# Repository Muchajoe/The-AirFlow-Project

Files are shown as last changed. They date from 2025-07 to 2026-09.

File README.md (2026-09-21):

# 💨 THE AIRFLOW PROJECT - ESP32 Smart Fan Controller






An ultra-compact (40x40 mm), intelligent 4-channel fan controller built for PC modding, SFF (Small Form Factor) builds, and smart home integration. **Please read this carefully!**

No proprietary desktop software required: just plug it in, connect to Wi-Fi, and take control immediately via Home Assistant or with your own Arduino code.

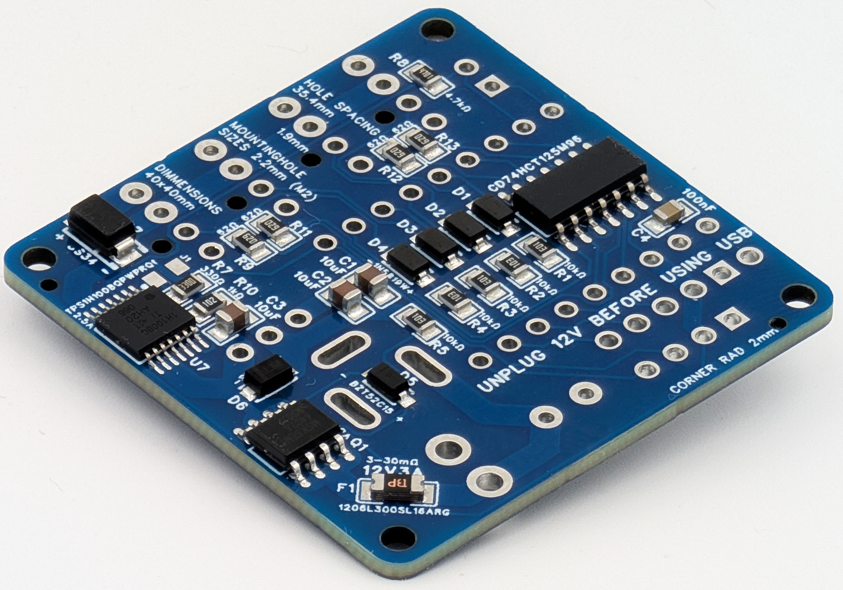
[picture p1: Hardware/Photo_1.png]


---

## 📑 Table of Contents

1. [The AirFlow Project Features](#-features-at-a-glance)
2. [DIY Expansion Port](#-the-hacker-header-diy-expansion-port)
3. [Socketed MCU Design)](#-modular-bring-your-own-brain-architecture)
4. [PWM Signal Integrity ](#-advanced-pwm-signal-integrity-true-5v-push-pull)
5. [Power Input Options](#-flexible-power-input-options)
6. [Hardware Protection](#%EF%B8%8F-ultimate-hardware-protection)
7. [Dimensions & Clearance](#-mechanical-dimensions--clearance)
8. [Getting Started](#-quick-start)
   - [ESPHome / Home Assistant](#option-a-esphome--home-assistant)
   - [Arduino](#option-b-the-arduino-way)
9. [Hardware & Pinout](#-hardware--pinout)
10. [Power Supply](#%EF%B8%8F-power-supply-safety-note)
11. [Troubleshooting](#troubleshooting)
12. [Important Words](#famous-and-important-last-words)
13. [Power Supply](#%EF%B8%8F-power-supply-safety-note)
14. [Troubleshooting](#troubleshooting)
15. [Where to buy (tindie.com)](https://www.tindie.com/products/the-omega-projects/the-airflow-project-esp32-pwm-fan-controller/)
15. [License](#%EF%B8%8F-license)

---

## ✨ Features at a Glance

* **The Brain:** Powered by a high-performance **ESP32-S3 Zero/Mini** (or optional ESP32C3 Zero/Mini or ESP32C6 Zero/Mini (NOT SuperMini)). Provides massive computing power for complex PID controllers, Wi-Fi, and Bluetooth.
* **4x Independent Channels:** Full PWM control and true RPM feedback (tacho signal) for up to four 12V fans.
* **Global Zero-RPM Mode:** Basic controllers often rely on a 0% PWM signal, which many fans ignore by dropping to a minimum idle speed. By acting as a master high-side switch, the eFuse allows the ESP32 to physically cut the 12V power to the entire fan rail at once – ensuring absolute 0dB silence for your whole setup when you don't need cooling.
* **Premium Power Delivery:** Instead of relying on cheap, heat-generating linear regulators (LDOs), this board features a high-end, fully encapsulated K7805-1000R3 switching regulator. This highly efficient (up to 96%) step-down converter guarantees a perfectly stable and icy-cool power supply for the ESP32-S3, ensuring rock-solid 24/7 reliability without any thermal issues. 
* **Overbuilt Power Delivery:** To ensure absolute thermal stability, the main 12V power traces are routed at a massive 1.9 mm width. Even running four [heavy-duty (noctua.at)](https://www.noctua.at/en/products/nf-f12-industrialppc-3000-pwm/specifications) fans at 100% capacity 24/7, the board remains completely cold, for a maximum lifespan of components.
* **Standardized Connectors:** Equipped with genuine Molex 4-pin headers (47053-1000) featuring friction locks. Fully compatible with all standard 4-pin PWM and 3-pin PC fans out of the box – no proprietary adapters required.
* **4x M2 Mounting Holes:** Despite the ultra-compact 40x40 mm footprint, the PCB features four precisely placed M2 mounting holes in the corners. Perfectly prepared for custom 3D-printed enclosures, brass standoffs, or direct integration into your custom PC or SFF chassis. Say goodbye to messy double-sided tape!
* **True Right to Repair (Self-Documenting PCB):** I believe hardware should be repairable. Instead of hiding component identities or forcing you to hunt through digital BOMs, the PCB silkscreen is exhaustively labeled. Every single component features its designator and, where applicable, its exact value printed right next to the pads. If you ever need to probe, modify, or repair the board, the PCB itself is your physical schematic.
* **One More Thing:** [If the airflow settles, there could be room for something brighter](OneMoreThing.md)<br>
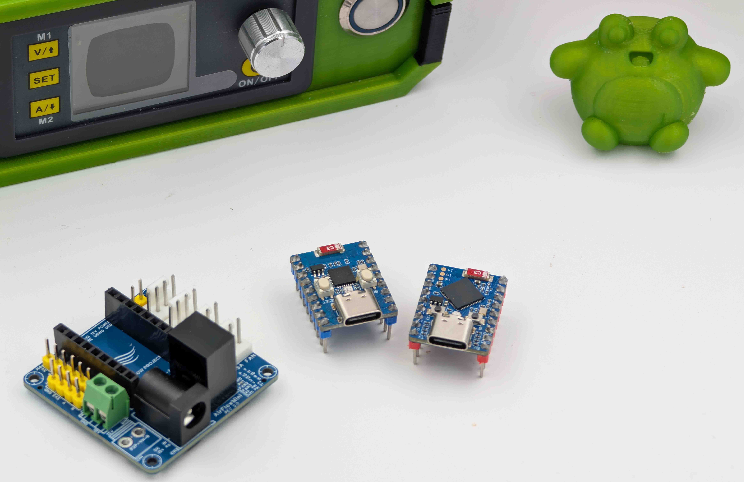
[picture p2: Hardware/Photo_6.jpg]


## 🧰 The "Hacker Header" (DIY Expansion Port)

While the controller is designed to work perfectly right out of the box, I wanted to leave the door wide open for maker, hardware hackers and modders. 

The board features an exposed male pin header that grants direct access to the ESP32's remaining resources:
* **Power Delivery:** Dedicated **5V, 3.3V, and GND** pins. You can power your external modules directly through the board's premium onboard voltage regulator.
* **5x Free GPIOs:** Fully routable pins ready for your custom physical interfaces.
* **Limitless Expansion:** Perfect for adding physical rotary encoders for manual speed tuning, tactile buttons, I2C OLED displays, or custom environmental/air quality sensors to trigger your fans automatically.
* **⚠️ Firmware Note:** Please be aware that this expansion header is provided purely as a hardware playground for tinkerers. These extra pins are *not* implemented in the stock web-interface firmware. They are waiting for you to unleash them via your own custom ESPHome configurations or C++ code!
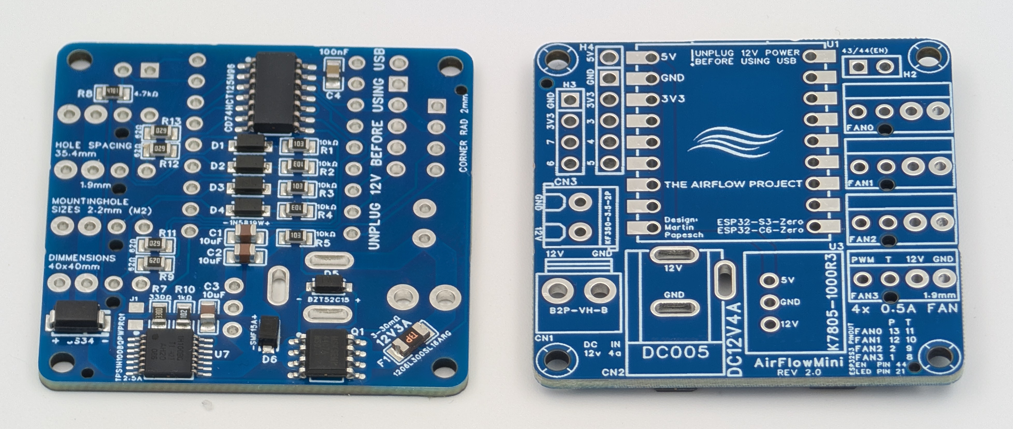
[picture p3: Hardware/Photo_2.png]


## 🧠 Modular "Bring Your Own Brain" Architecture

This board features a **socketed MCU design** based on the popular "Zero" form factor. You own the hardware, and you decide what runs on it.

* **The Default Powerhouse:** The board is designed around the **ESP32-S3 Zero**, providing massive computing power, Wi-Fi, and Bluetooth 5 (LE) for complex local web interfaces and advanced PID fan control.
* **Drop-In Upgrades:** The socket is fully pin-compatible with other microcontrollers in the same form factor, such as the **ESP32-C3 Zero** or **ESP32-C6 Zero**.
* **Next-Gen Smart Home Ready:** By simply swapping the default MCU for an ESP32-C6 Zero, your hardware immediately gains support for **IEEE 802.15.4** wireless standards. This unlocks the physical ability to integrate the controller directly into modern power saving mesh networks!

## 🌊 Advanced PWM Signal Integrity (True 5V Push-Pull)

The original Intel 4-pin fan specification from the early 2000s relies on an open-drain architecture: the controller pulls the PWM signal to Ground and lets it "float" back up, relying entirely on the fan's internal pull-up resistor. While adequate for basic setups, this floating approach often results in degraded, sloppy signal waves—especially when using longer cable runs.

To guarantee flawless motor control, this board utilizes a dedicated **CD74HCT125M96** logic buffer to deliver a strict **5V Push-Pull** PWM signal. 

* **Perfect Square Waves:** Instead of floating, the IC actively drives the signal high (5V) and aggressively pulls it low (GND). This ensures perfectly sharp signal edges and totally eliminates RPM fluctuations or motor clicking.
* **Modern Industry Standards:** This robust, active signaling approach is designed in accordance with modern high-end cooling standards, perfectly satisfying the strict electrical requirements detailed in [Noctua's PWM Specifications White Paper](https://cdn.noctua.at/media/Noctua_PWM_specifications_white_paper.pdf).<br><br>
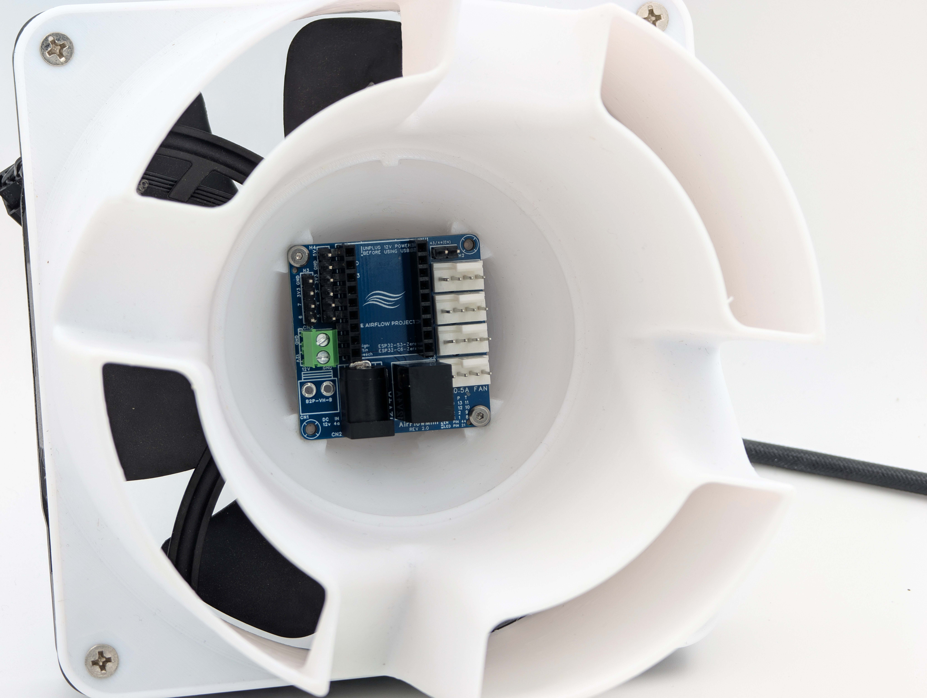
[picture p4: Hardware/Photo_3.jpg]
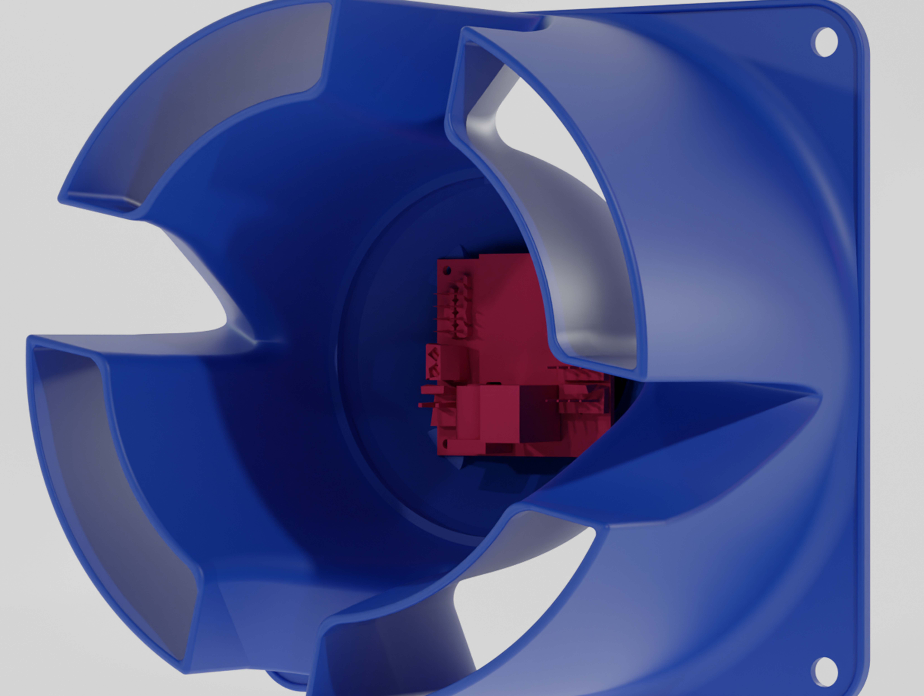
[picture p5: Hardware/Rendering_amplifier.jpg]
<br>
[The AirFlowProject Remix of Noctua's Amplifier 3D File (printables.com)](https://www.printables.com/model/1357774-the-airflow-project-140mm-air-amplifier-integrated)

## 🔌 Flexible Power Input Options

No two projects are the same. Whether you are building a standalone desk fan, upgrading a 3D printer, or wiring a custom server rack, you can choose the 12V power input connector that fits your needs:

* **DC Barrel Jack (~~DC005~~ PJ-002AH):** The classic 5.5x2.1mm plug. Perfect for standard 12V wall power adapters.
* **Screw Terminal (KF350-3.5-2P):** The tinkerer's choice. Ideal for bare wires, ferrules, and custom industrial setups.
* **JST-VH Latching Header (B2P-VH):** A highly secure, locking connector that won't come loose – perfect for custom PC wire harnesses or environments with vibration.

*Note: The board is engineered with a single-sided SMT layout.*<br>
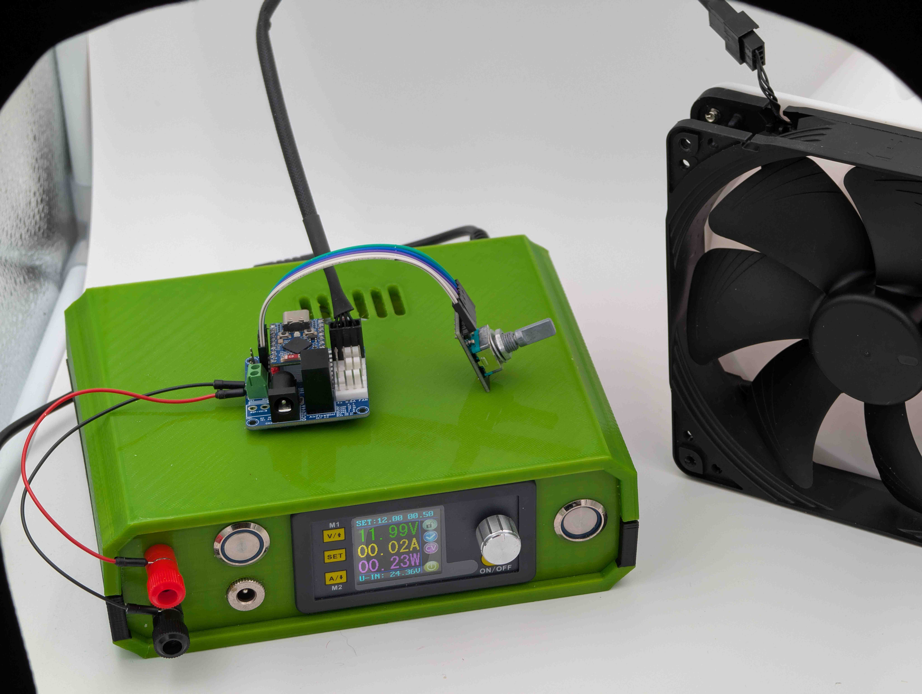
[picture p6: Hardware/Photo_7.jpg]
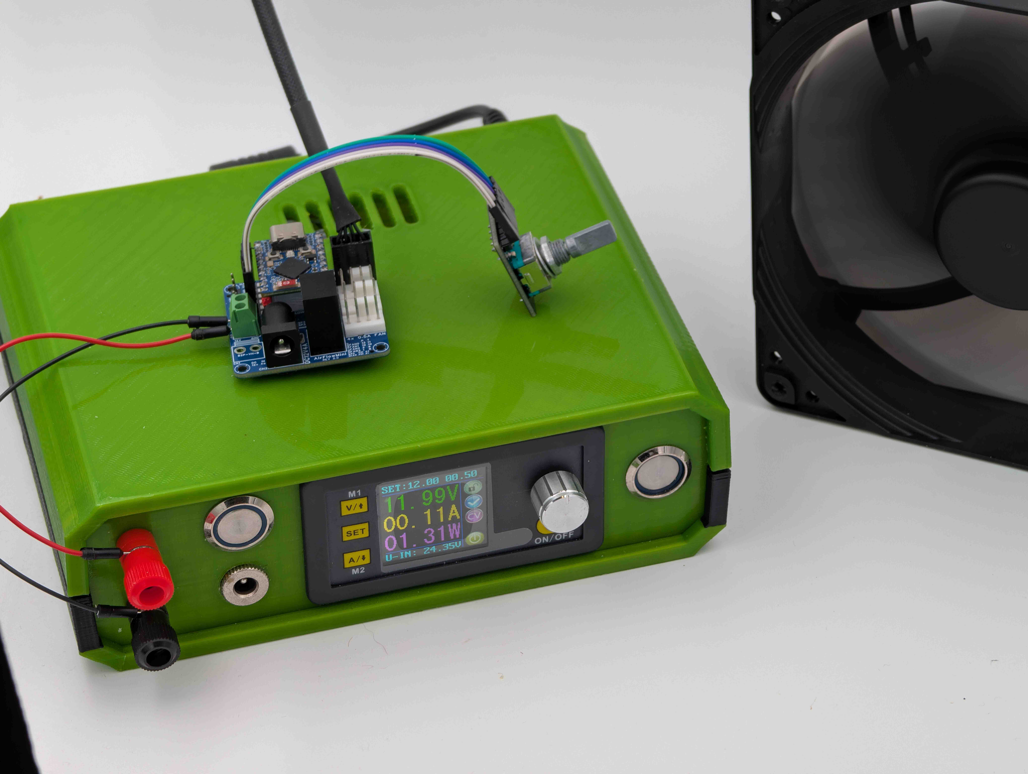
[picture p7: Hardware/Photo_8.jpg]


## 🛡️ Ultimate Hardware Protection

Most DIY controllers cut costs on protection. This board features a multi-layered, industrial-grade defense system to ensure absolute safety for your fans, the board, and your power supply:

* **Reverse Polarity Protection:** A dedicated AO4407A P-Channel MOSFET ensures that plugging the 12V input in backwards won't fry the board, while maintaining near-zero voltage drop and heat generation.
* **Industrial Protection (eFuse):** A dedicated Texas Instruments TPS1H100-Q1 chip protects your fans, the board traces, and your power supply. It features a strict hardware-level cutoff at **2.5 Amps** to prevent any damage from shorted fan cables or blocked motors.
* **Dual Overcurrent Protection:** A secondary 1206 Resettable PTC Fuse acts as an ultimate fail-safe backup on the main power line.
* **Clean Power (Freewheeling):** An SS34 Schottky diode safely absorbs destructive inductive kickback (flyback voltage) generated by the fan motor coils during PWM switching.
* **ESD & Transient Protection (Only Revision 2.1 or newer):** A combined defense using an SMF15A TVS diode and a BZT52C15 Zener diode aggressively clamps down sudden voltage spikes from the power supply or static discharge. This dual-stage approach fully protects both the power-entry circuitry and the sensitive core logic.
* **3.3V Logic Clamping:** 1N5819W Schottky diodes on the RPM (tacho) input pins strictly prevent any stray 12V signals from the fans from reaching and destroying the ESP32's sensitive 3.3V logic.
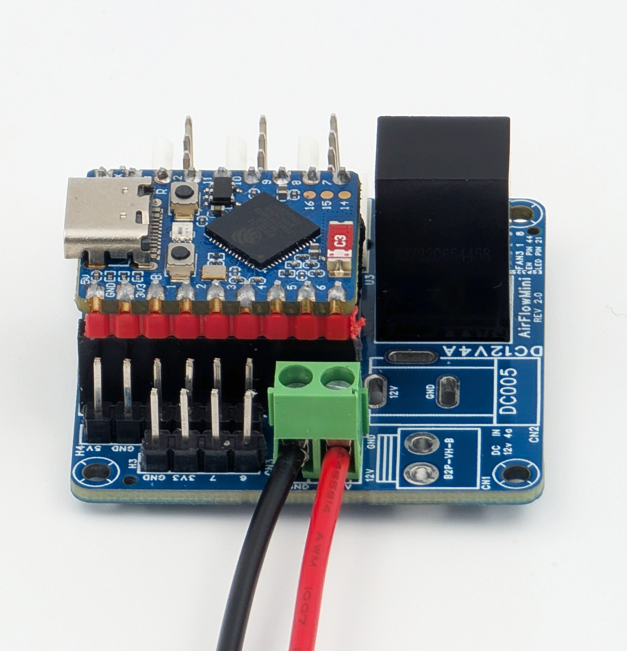
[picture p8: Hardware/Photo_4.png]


## 📐 Mechanical Dimensions & Clearance

The board is designed for compact SFF (Small Form Factor) environments. Please note the following dimensions for your enclosure design:

* **Board Size (Outline):** 40 x 40 mm
   * The USB-C port of the ESP32 Zero extends approximately 1 mm beyond the PCB edge.
* **PCB Thickness:** 1.6 mm
* **Mounting Holes:** 4x M2 holes, spaced at 35.4 x 35.4 mm (measured from center to center).
* **Component Height (Front/Top):** 
    * The tallest component is ~18 mm.
    * *Note:* Please ensure extra vertical clearance to account for the height of the Molex 4-pin fan connectors (Fan side).
* **Component Height (Back/Bottom):** Maximum component profile is ~3 mm. Ensure adequate standoff distance (e.g., using 5mm standoffs) if mounting on a flat metal surface to avoid short circuits.
You can find a 3D file of the PCB [here](/Hardware/README.md). That may be help you design a costom housing. 
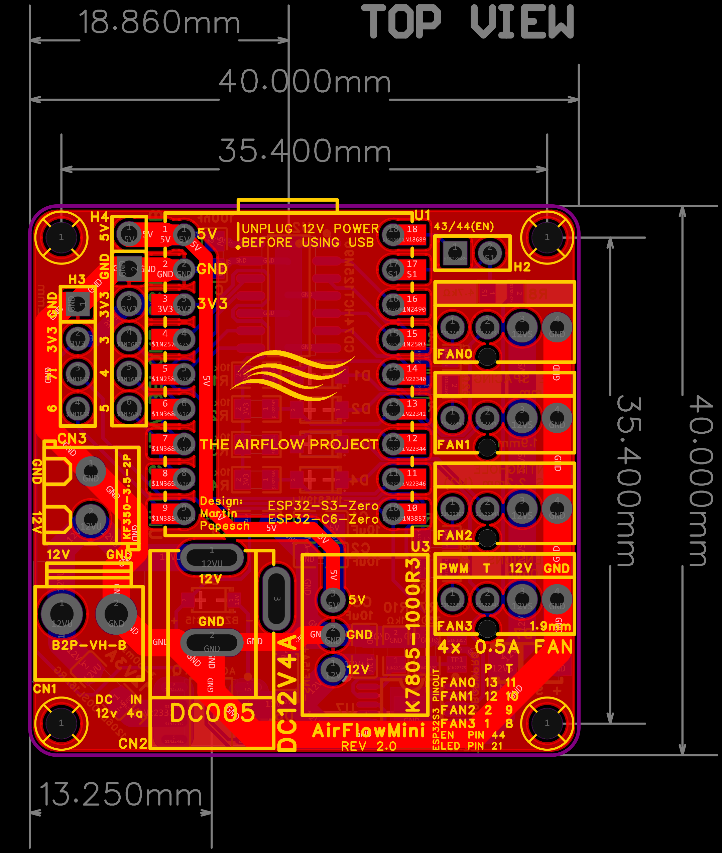
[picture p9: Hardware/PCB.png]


---

## 🚀 Quick Start

You have two ways to get the board up and running:

### Option A: ESPHome / Home Assistant
Perfect for smart home enthusiasts. Simply flash our pre-configured `.yaml` file to the board, and your fans will automatically appear in Home Assistant.<br>
_INFO: This configuration switches the Fan power automatically. If one or more fans are set to more than 0% PWM it switches the Fan power rail on_<br>
👉 [Get the esphome.yaml here](/Firmware/ESPHome)<br>
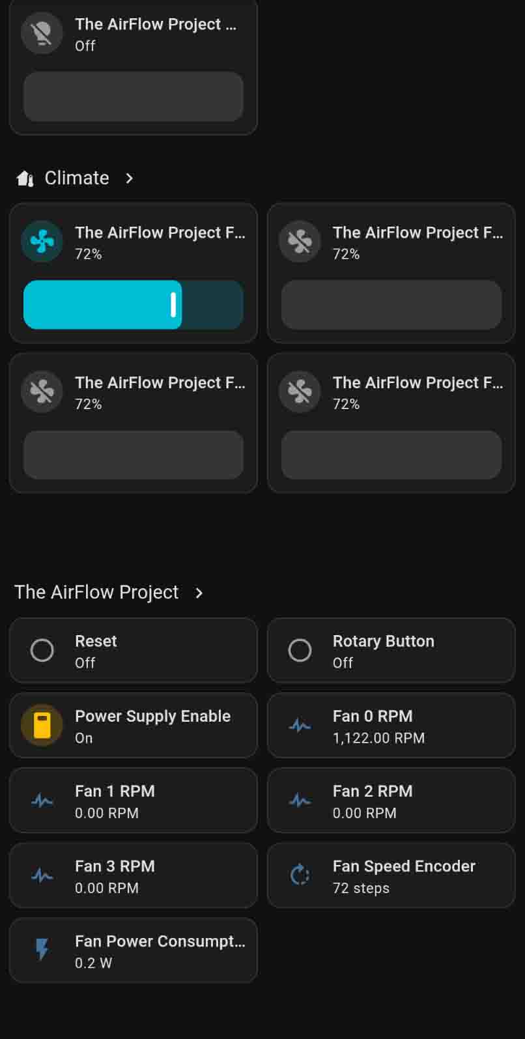
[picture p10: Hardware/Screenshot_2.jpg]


### Option B: The Arduino way
Use the code example to understand the logic and write your own code to get exactly what you need for your special demand.<br>
👉 [Arduino Examples](/Firmware/Arduino)<br>
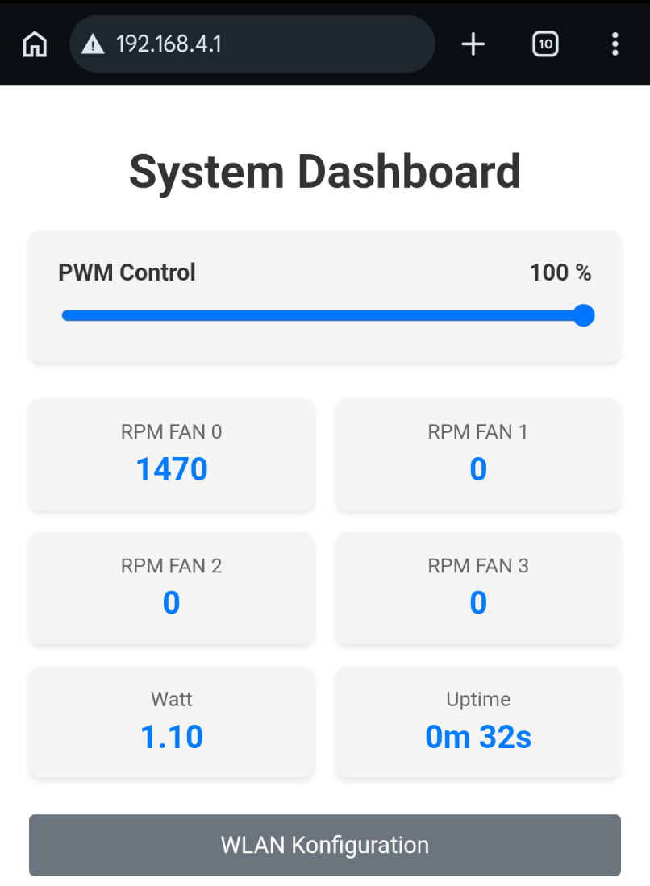
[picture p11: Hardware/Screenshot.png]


---

## 🔌 Hardware & Pinout
### Hardware
You will find the whole component list here (Bill of materials (BOM)) and the known issues here:<br>
👉 [BOM, Schematics and Known issues](/Hardware/README.md)<br>
👉 [Changelog](CHANGELOG.md)<br><br>

### Pinout<br>

| Board PIN | ESP32S3 PIN| ESP32C3 PIN| ESP32C6 PIN|
| --- |:---:|:---:|:---:|
| Enable | 44 |SOON|SOON|
| FAN0 | 13 |SOON|SOON|
| RPM0 | 11 |SOON|SOON|
| FAN1 | 12 |SOON|SOON|
| RPM1 | 10 |SOON|SOON|
| FAN2 | 2 |SOON|SOON|
| RPM2 | 9 |SOON|SOON|
| FAN3 | 1 |SOON|SOON|
| RPM3 | 8 |SOON|SOON|
| RGB LED | 21 |SOON|SOON|
| H3 PIN6 | 6 |SOON|SOON|
| H3 PIN7 or CS | 7 |SOON|SOON|
| H4 PIN5 | 5 |SOON|SOON|
| H4 PIN4 | 4 |SOON|SOON|
| H4 PIN3 | 3 |SOON|SOON|

It may be possible to use a ESP32C6 XIAO. You must mount it upside down (5v, GND, 3.3V Pins must match the board labeled 5v, GND, 3.3v). And you dont have the full features (because of the missing pins obviously)
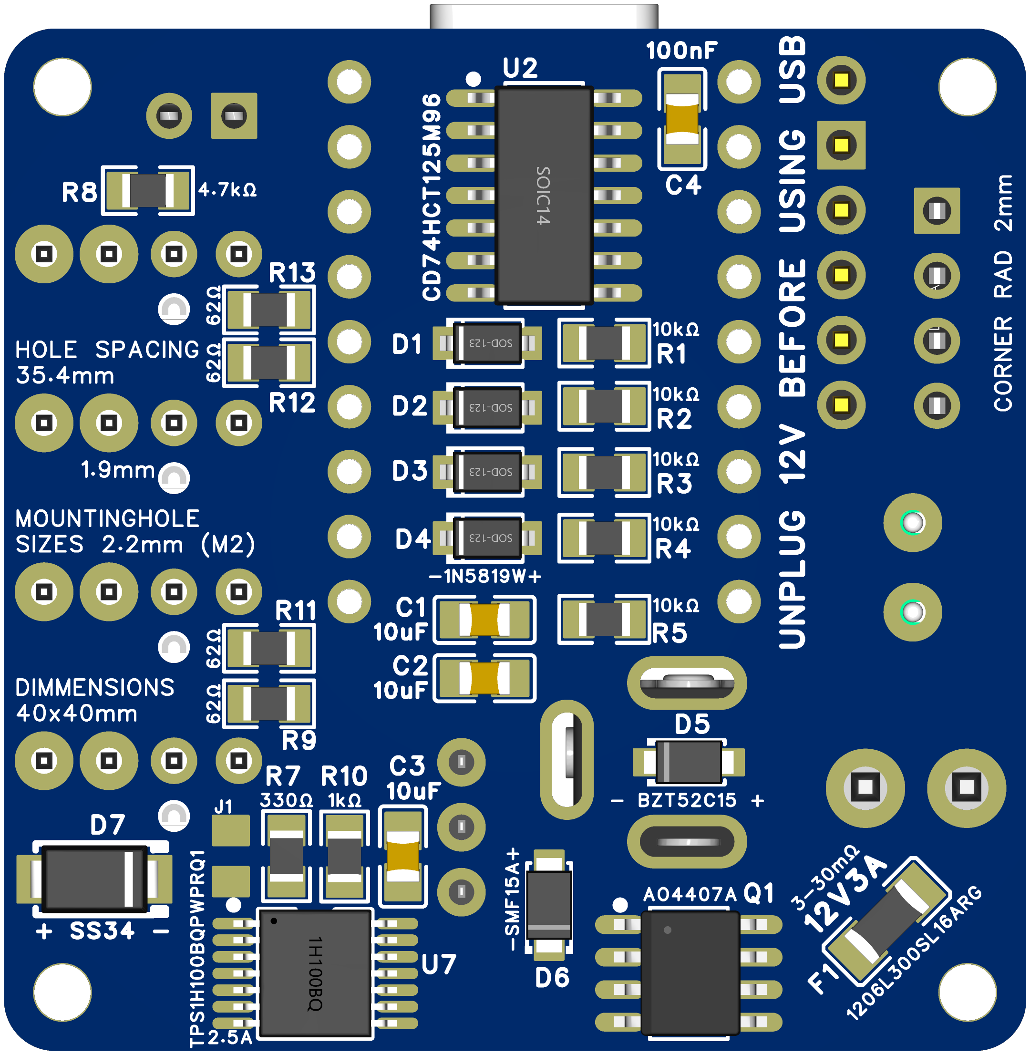
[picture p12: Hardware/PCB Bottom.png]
PCB Bottom


### The Solder Jumper (Optional Pin vs. Current Sense)
To maximize the limited GPIOs of the ESP32-S3, the board features a solder jumper (J1):
* **Position "Default":** H3 Pin7 is one of five Pins for optional hardware (Rotary encode, Button, Sensors).
* **Position "CS" (bridged):** Sacrifices the H3 Pin7, but connects the ESP32 GPIO7 directly to the analog current-sense output of the eFuse for live telemetry and software-based short-circuit detection. IMPORTANT do not connect anything to H3 Pin7 anymore.<br>
_This analog measurement is designed for rough telemetry, not high-precision metering. At very low currents (e.g., fans running slowly or turned off), the TI eFuse enters an "Open-Load" fault state and outputs a high diagnostic voltage (~3V) instead of a real reading. To prevent massive false power spikes in your dashboard, your firmware must be configured to treat any raw voltage above ~2.5V as 0W._<br>
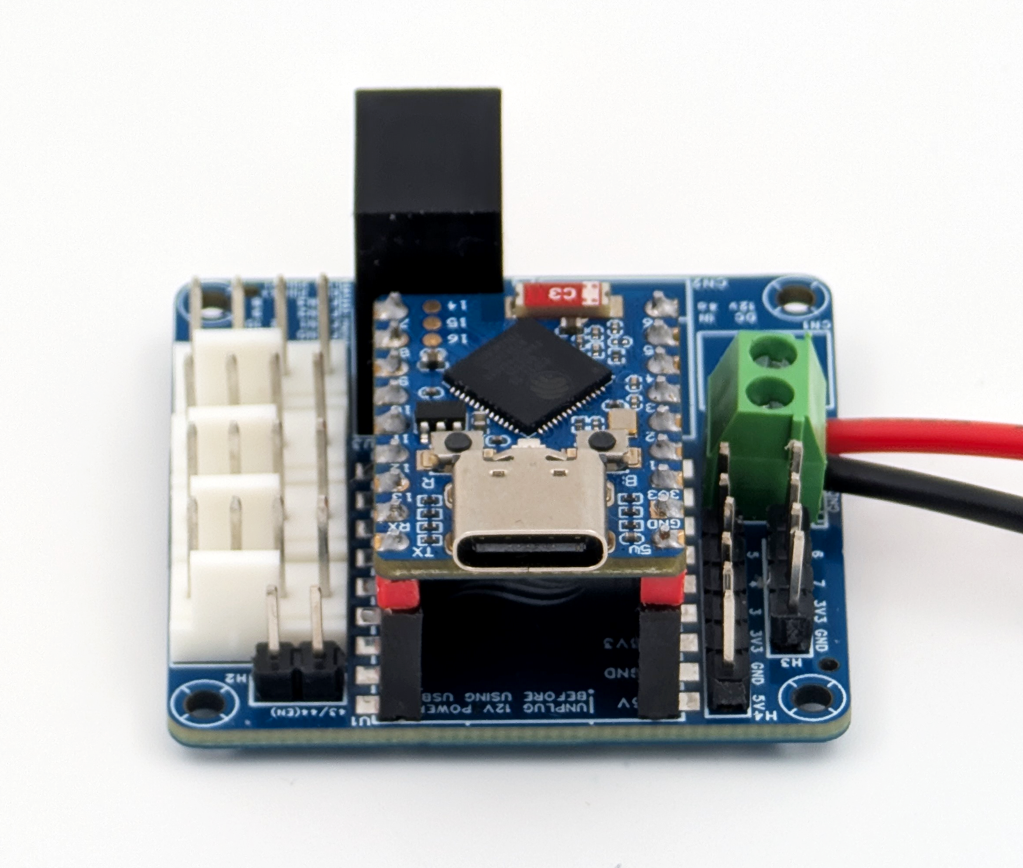
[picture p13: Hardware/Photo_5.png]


### ⚠️ Power Supply Safety Note
Please use a high quality 12v 4a Power supply.
The board is equipped with a strict **2.5A (FAN CURRENT) hardware limit**. This is more than enough for four standard 120/140mm PC fans running at full speed. Do **not** connect water cooling pumps (like a D5), as their high startup current will immediately trigger the eFuse's 2.5A limit. **If you are using the DC005, keep in mind that this connector supports only up to 2.5 amps.**

## Troubleshooting
Is something not working? Take a look here:
👉 [Troubleshooting](Troubleshooting)<br>
You are searching for a replacement part:
👉 [BOM](/Hardware/README.md)<br>
Some isssues are known and we will work on that for future revisions:
👉 [Known issues](/Hardware/README.md)<br>
Here you will find the schematics:
👉 [Schematics](/Hardware/README.md)<br>

---

## Famous and Important last words
* **REV 2.0:**<br>
**!!! IMPORTANT: UNMOUNT THE ESP32 Before USING USB !!!**
If you are using the USB from the mounted ESP32 there could be a Backfeeding. That means in this moment your USB will power up the whole pcb and that could possibly overload your USB Port or damages the ESP32 Hardware. It is strictly recommended to physically unmount the ESP32 from the PCB before using the USB for flashing. A OTA update function could be a good solution for this. **!!! In any case  disconnect the 12v Power supply. Before using the USB Port !!!** I am working on that for future revisions to fix this behavior for newer boards (Rev 2.1)

---

**If you have any questions or feedback, feel free to open an issue!**

---

## ⚖️ License

This project uses a split-licensing model to keep the software open for the community while protecting the hardware design.

*   **Software / Firmware:** Released under the [MIT License](LICENSE-SOFTWARE).
*   **Hardware Design (Schematics):** Released under the [Creative Commons Attribution-NonCommercial-NoDerivatives 4.0 International (CC BY-NC-ND 4.0)](https://creativecommons.org/licenses/by-nc-nd/4.0/) License. You may view and study the schematics, but you may not modify them or use them for commercial purposes without explicit permission.
*   **Media:** All photos, graphics, and logos in this repository are **All Rights Reserved** and may not be used commercially or to promote derivative hardware projects.

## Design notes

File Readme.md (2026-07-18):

# 💨 THE AIRFLOW PROJECT - ESP32-S3 Smart Fan Controller

An ultra-compact (40x40 mm), intelligent 4-channel fan controller built for PC modding, SFF (Small Form Factor) builds, and smart home integration. Designed with a focus on industrial-grade hardware protection. 

No proprietary desktop software required: just plug it in, connect to Wi-Fi, and take control immediately via the built-in web interface or Home Assistant.

SOON!

---

## ✨ Features at a Glance

* **The Brain:** Powered by a high-performance **ESP32-S3 Zero/Mini** (or optional ESP32C3 Zero/Mini or ESP32C6 Zero/Mini (NOT SuperMini)). Provides massive computing power for complex PID controllers, Wi-Fi, and Bluetooth.
* **4x Independent Channels:** Full PWM control and true RPM feedback (tacho signal) for up to four 12V fans.
* **Global Zero-RPM Mode:** Basic controllers often rely on a 0% PWM signal, which many fans ignore by dropping to a minimum idle speed. By acting as a master high-side switch, the eFuse allows the ESP32 to physically cut the 12V power to the entire fan rail at once – ensuring absolute 0dB silence for your whole setup when you don't need cooling.
* **Premium Power Delivery:** Instead of relying on cheap, heat-generating linear regulators (LDOs), this board features a high-end, fully encapsulated K7805-1000R3 switching regulator. This highly efficient (up to 96%) step-down converter guarantees a perfectly stable and icy-cool power supply for the ESP32-S3, ensuring rock-solid 24/7 reliability without any thermal issues. 
* **Overbuilt Power Delivery:** To ensure absolute thermal stability, the main 12V power traces are routed at a massive 1.9 mm width. Even running four heavy-duty fans at 100% capacity 24/7, the board remains completely cold, for a maximum lifespan of components.
* **Standardized Connectors:** Equipped with genuine Molex 4-pin headers (47053-1000) featuring friction locks. Fully compatible with all standard 4-pin PWM and 3-pin PC fans out of the box – no proprietary adapters required.
* **4x M2 Mounting Holes:** Despite the ultra-compact 40x40 mm footprint, the PCB features four precisely placed M2 mounting holes in the corners. Perfectly prepared for custom 3D-printed enclosures, brass standoffs, or direct integration into your custom PC or SFF chassis. Say goodbye to messy double-sided tape!
* **True Right to Repair (Self-Documenting PCB):** I believe hardware should be open and repairable. Instead of hiding component identities or forcing you to hunt through digital BOMs, the PCB silkscreen is exhaustively labeled. Every single component features its designator and, where applicable, its exact value printed right next to the pads. If you ever need to probe, modify, or repair the board, the PCB itself is your physical schematic.

## 🧰 The "Hacker Header" (DIY Expansion Port)

While the controller is designed to work perfectly right out of the box, I wanted to leave the door wide open for maker, hardware hackers and modders. 

The board features an exposed male pin header that grants direct access to the ESP32's remaining resources:
* **Power Delivery:** Dedicated **5V, 3.3V, and GND** pins. You can power your external modules directly through the board's premium onboard voltage regulator.
* **5x Free GPIOs:** Fully routable pins ready for your custom physical interfaces.
* **Limitless Expansion:** Perfect for adding physical rotary encoders for manual speed tuning, tactile buttons, I2C OLED displays, or custom environmental/air quality sensors to trigger your fans automatically.
* **⚠️ Firmware Note:** Please be aware that this expansion header is provided purely as a hardware playground for tinkerers. These extra pins are *not* implemented in the stock web-interface firmware. They are waiting for you to unleash them via your own custom ESPHome configurations or C++ code!

## 🧠 Modular "Bring Your Own Brain" Architecture

This board features a **socketed MCU design** based on the popular "Zero" form factor. You own the hardware, and you decide what runs on it.

* **The Default Powerhouse:** The board is designed around the **ESP32-S3 Zero**, providing massive computing power, Wi-Fi, and Bluetooth 5 (LE) for complex local web interfaces and advanced PID fan control.
* **Drop-In Upgrades:** The socket is fully pin-compatible with other microcontrollers in the same form factor, such as the **ESP32-C3 Zero** or **ESP32-C6 Zero**.
* **Next-Gen Smart Home Ready:** By simply swapping the default MCU for an ESP32-C6 Zero, your hardware immediately gains support for **IEEE 802.15.4** wireless standards. This unlocks the physical ability to integrate the controller directly into modern Thread, Matter, or Zigbee mesh networks!

## 🌊 Advanced PWM Signal Integrity (True 5V Push-Pull)

The original Intel 4-pin fan specification from the early 2000s relies on an open-drain architecture: the controller pulls the PWM signal to Ground and lets it "float" back up, relying entirely on the fan's internal pull-up resistor. While adequate for basic setups, this floating approach often results in degraded, sloppy signal waves—especially when using longer cable runs.

To guarantee flawless motor control, this board utilizes a dedicated **CD74HCT125M96** logic buffer to deliver a strict **5V Push-Pull** PWM signal. 

* **Perfect Square Waves:** Instead of floating, the IC actively drives the signal high (5V) and aggressively pulls it low (GND). This ensures perfectly sharp signal edges and totally eliminates RPM fluctuations or motor clicking.
* **Modern Industry Standards:** This robust, active signaling approach is designed in accordance with modern high-end cooling standards, perfectly satisfying the strict electrical requirements detailed in [Noctua's PWM Specifications White Paper](https://cdn.noctua.at/media/Noctua_PWM_specifications_white_paper.pdf).

## 🔌 Flexible Power Input Options

No two projects are the same. Whether you are building a standalone desk fan, upgrading a 3D printer, or wiring a custom server rack, you can choose the 12V power input connector that fits your needs:

* **DC Barrel Jack (DC005) [Default]:** The classic 5.5x2.1mm plug. Perfect for standard 12V wall power adapters.
* **Screw Terminal (KF350-3.5-2P) [Optional]:** The tinkerer's choice. Ideal for bare wires, ferrules, and custom industrial setups.
* **JST-VH Latching Header (B2P-VH) [Optional]:** A highly secure, locking connector that won't come loose – perfect for custom PC wire harnesses or environments with vibration.

*Note: The board is engineered with a single-sided SMT layout. By keeping all high-end SMD components on the bottom  layer, production costs at JLCPCB are kept efficient, allowing us to deliver an industrial-grade, highly protected board at an accessible price.*

## 🛡️ Ultimate Hardware Protection

Most DIY controllers cut costs on protection. This board features a multi-layered, industrial-grade defense system to ensure absolute safety for your fans, the board, and your power supply:

* **Reverse Polarity Protection:** A dedicated AO4407A P-Channel MOSFET ensures that plugging the 12V input in backwards won't fry the board, while maintaining near-zero voltage drop and heat generation.
* **Industrial Protection (eFuse):** A dedicated Texas Instruments TPS1H100-Q1 chip protects your fans, the board traces, and your power supply. It features a strict hardware-level cutoff at exactly **2 Amps** to prevent any damage from shorted fan cables or blocked motors.
* **Dual Overcurrent Protection:** A secondary 1206 Resettable PTC Fuse acts as an ultimate fail-safe backup on the main power line.
* **Clean Power (Freewheeling):** An SS34 Schottky diode safely absorbs destructive inductive kickback (flyback voltage) generated by the fan motor coils during PWM switching.
* **Overvoltage & ESD Spikes:** SMF15A TVS and BZT52C15 Zener diodes aggressively clamp down any sudden voltage spikes from your power supply or static discharge.
* **3.3V Logic Clamping:** 1N5819W Schottky diodes on the RPM (tacho) input pins strictly prevent any stray 12V signals from the fans from reaching and destroying the ESP32's sensitive 3.3V logic.

## 📐 Mechanical Dimensions & Clearance

The board is designed for compact SFF (Small Form Factor) environments. Please note the following dimensions for your enclosure design:

* **Board Size (Outline):** 40 x 40 mm
   * The USB-C port of the ESP32 Zero extends approximately 1 mm beyond the PCB edge.
* **PCB Thickness:** 1.6 mm
* **Mounting Holes:** 4x M2 holes, spaced at 35.4 x 35.4 mm (measured from center to center).
* **Component Height (Front/Top):** 
    * The tallest component is ~18 mm.
    * *Note:* Please ensure extra vertical clearance to account for the height of the Molex 4-pin fan connectors (Fan side).
* **Component Height (Back/Bottom):** Maximum component profile is ~3 mm. Ensure adequate standoff distance (e.g., using 5mm standoffs) if mounting on a flat metal surface to avoid short circuits.

---

## 🚀 Quick Start

You have two ways to get the board up and running:

### Option A: ESPHome / Home Assistant SOON!
Perfect for smart home enthusiasts. Simply flash our pre-configured `.yaml` file to the board, and your fans will automatically appear in Home Assistant.
👉 [Get the esphome.yaml here](/esphome/fan_controller.yaml)

### Option B: The Standalone Web-Interface SOON!
Power up the board, and it will open its own Wi-Fi Access Point. Connect to it, enter your local Wi-Fi credentials, and configure your fan curves directly from your browser. 
👉 [Web-Interface Documentation]([LINK_TO_WIKI_OR_FILE])

---

## 🔌 Hardware & Pinout

| Board PIN | ESP32S3 PIN| ESP32C3 PIN| ESP32C6 PIN|
| --- |:---:|:---:|:---:|
| Enable | 44 |:-------------:|:-------------:|
| FAN0 | 13 |:-------------:|:-------------:|
| RPM0 | 11 |:-------------:|:-------------:|
| FAN1 | 12 |:-------------:|:-------------:|
| RPM1 | 10 |:-------------:|:-------------:|
| FAN2 | 2 |:-------------:|:-------------:|
| RPM2 | 9 |:-------------:|:-------------:|
| FAN3 | 1 |:-------------:|:-------------:|
| RPM3 | 8 |:-------------:|:-------------:|
| RGB LED | 21 |:-------------:|:-------------:|
| H3 PIN6 | 6 |:-------------:|:-------------:|
| H3 PIN7 | 7 |:-------------:|:-------------:|
| H4 PIN5 | 5 |:-------------:|:-------------:|
| H4 PIN4 | 4 |:-------------:|:-------------:|
| H4 PIN3 | 3 |:-------------:|:-------------:|

You can also use a ESP32C6 XIAO. You must mount it upside down (5v, GND, 3,3V Pins must match the board label). And you dont have the full features (because of the missing pins obviously)

### The Solder Jumper (Optional Pin vs. Current Sense)
To maximize the limited GPIOs of the ESP32-S3, the board features a solder jumper (J1):
* **Position "Default":** H3 Pin4 is one of five Pins for optional hardware (Rotary encode, Button, Sensors).
* **Position "CS" (bridged):** Sacrifices the H3 Pin4, but connects the ESP32 directly to the analog current-sense output of the eFuse for live telemetry and software-based short-circuit detection. IMPORTANT do not connect anything to H3 Pin4 anymore.

### ⚠️ Power Supply Safety Note
Please use a high quality 12v 4a Power supply.
The board is equipped with a strict **2A hardware limit**. This is more than enough for four standard 120/140mm PC fans running at full speed. Do **not** connect water cooling pumps (like a D5), as their high startup current will immediately trigger the eFuse's 2A limit.

**!!! IMORTANT: UNPLUG THE 12V POWER SUPPLY BEFORE PLUG IN THE USB !!!** 
---

**If you have any questions or feedback, feel free to open an issue!**

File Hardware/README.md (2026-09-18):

# Hardware Overview
This includes a overview where you can find the bom (bill of material) and known issues and schematics and the changelog<br><br>

### 👉 [Changelog](/CHANGELOG.md)<br><br>
#### 👉 [REV 2.0 BOM](/Hardware/REV2.0/bom%20REV2.0.md) 👉 [REV 2.0 Known issues](https://github.com/Muchajoe/The-AirFlow-Project/issues/2) 👉 [REV 2.0 Schematics](/Hardware/REV2.0/schematic%20REV2.0.pdf)👉 [REV 2.0 3D File](/Hardware/REV2.0/pcb%20REV2.0.stl)<br>

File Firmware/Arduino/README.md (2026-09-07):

# Example Overview (Arduino)
## The Quick and Simple
Is a easy code to make it move. It simply starts the Fans at 100% and waits 10 seconds. Then it set the PWM signal to 0. Some Fans will stop spinning here. Others will continue spinning at the lowest possible speed of the fan. After 1ß seconds the PCB will cut the 12V Power supply to the FANs. That will stop every FAN.

## Rotary Example
In this example you need a rotary encoder. By Spin the rotary you can set a fan speed. At Zero PWM the logic will cut the 12v automaticly. It also uses the RGB onboard led to indicate the state. Red means that the maximum is arrived. Green means the minimum is arrived. Blue is all inbetween.

## Rotary and WebUI Example (proof of concept)
That includes the Rotary example and adds a WebUi. After flashing this you should be able to connect to a wlan called **"The Airflow Project"** with a password of **"TheAirFlowSetup"**. It will also read out the RPM and it will also try to readout the Wattage (that only works if you have bridged the J1 Jumper on the PCB). If you want to use a rotary encoder:
| Encoder Pin | Airflow Pin| 
| --- |:---:|
| GND | GND |
| + (3.3 or VIN) | 3.3V |
| SW | 3 |
| DT | 4 |
| CLK | 5 |

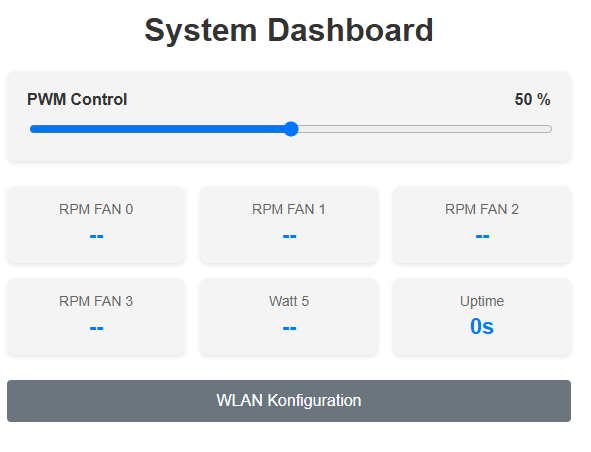
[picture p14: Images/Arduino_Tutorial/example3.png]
Arduino step 1


## Arduino Quickstart
1. You need the Arduino IDE. Open The board Manager (left side). Type in ESP and Download the ESP32 Core.
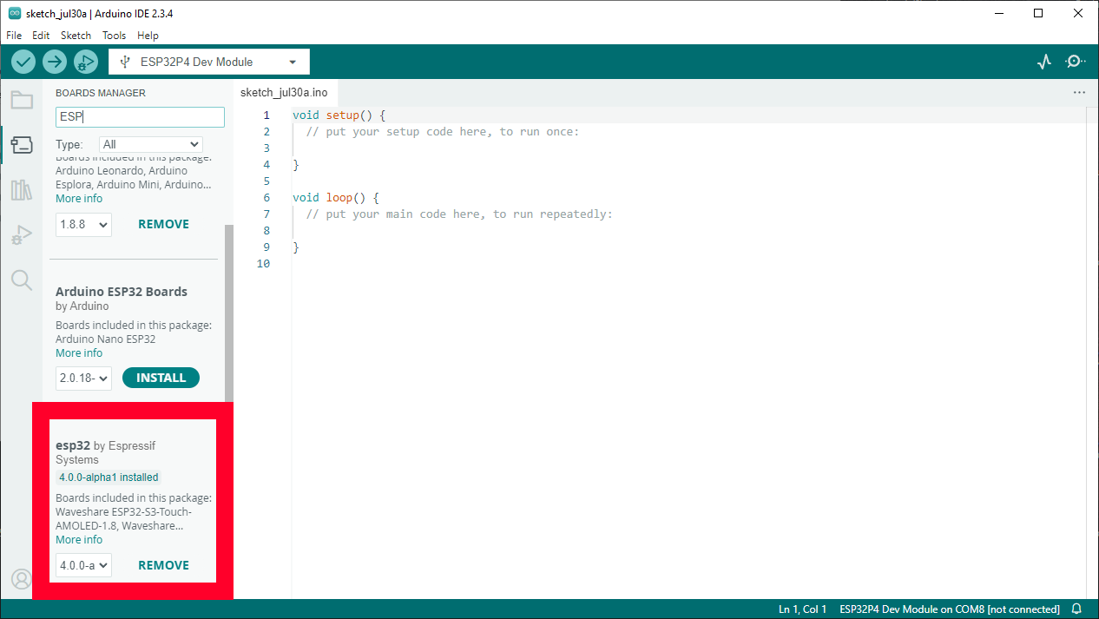
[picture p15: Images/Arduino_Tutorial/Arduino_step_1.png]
Arduino step 1


2. Fot the Rotary and WebUI example you need to install the Websockets Library by Markus Sattler You will find it by typing in Websockets in the library manager
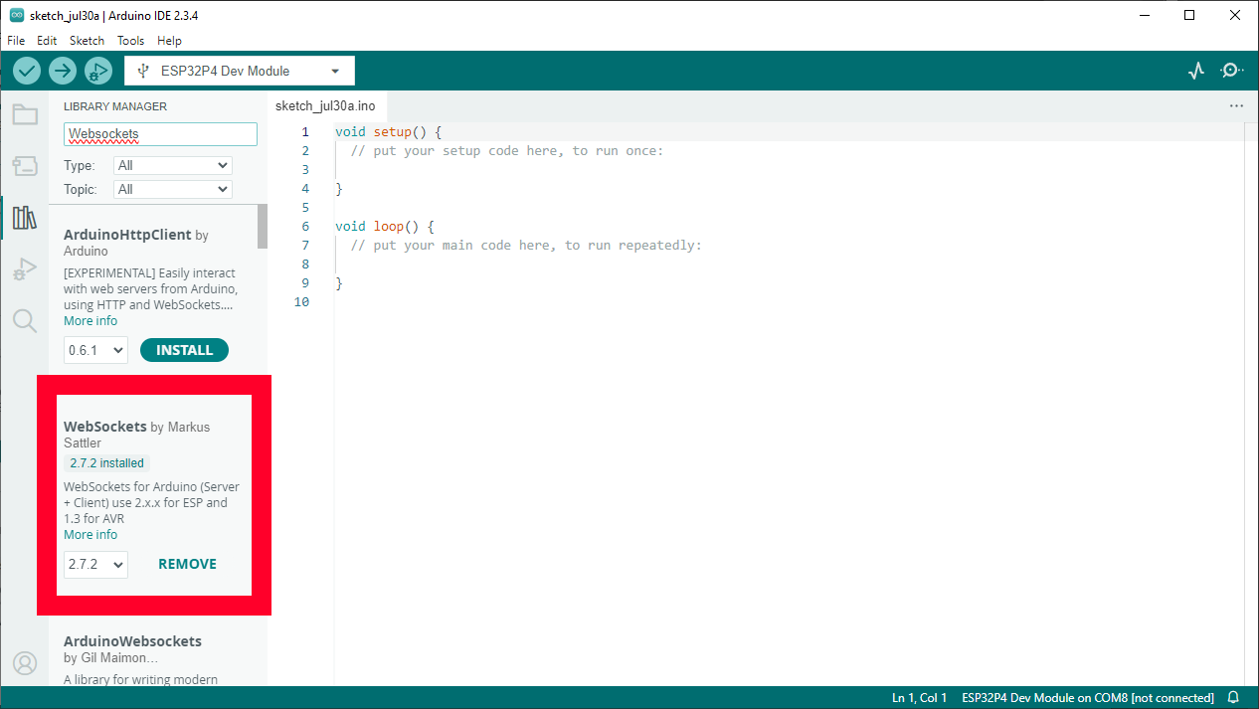
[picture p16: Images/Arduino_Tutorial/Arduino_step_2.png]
Arduino step 2


3. Choose your ESP32 board. I like to use one of the pre configured ESP32S3 Zero or Mini variant. And Enable USB CDC to activate the Serial Monitor funxionallity. And choose the right com port.
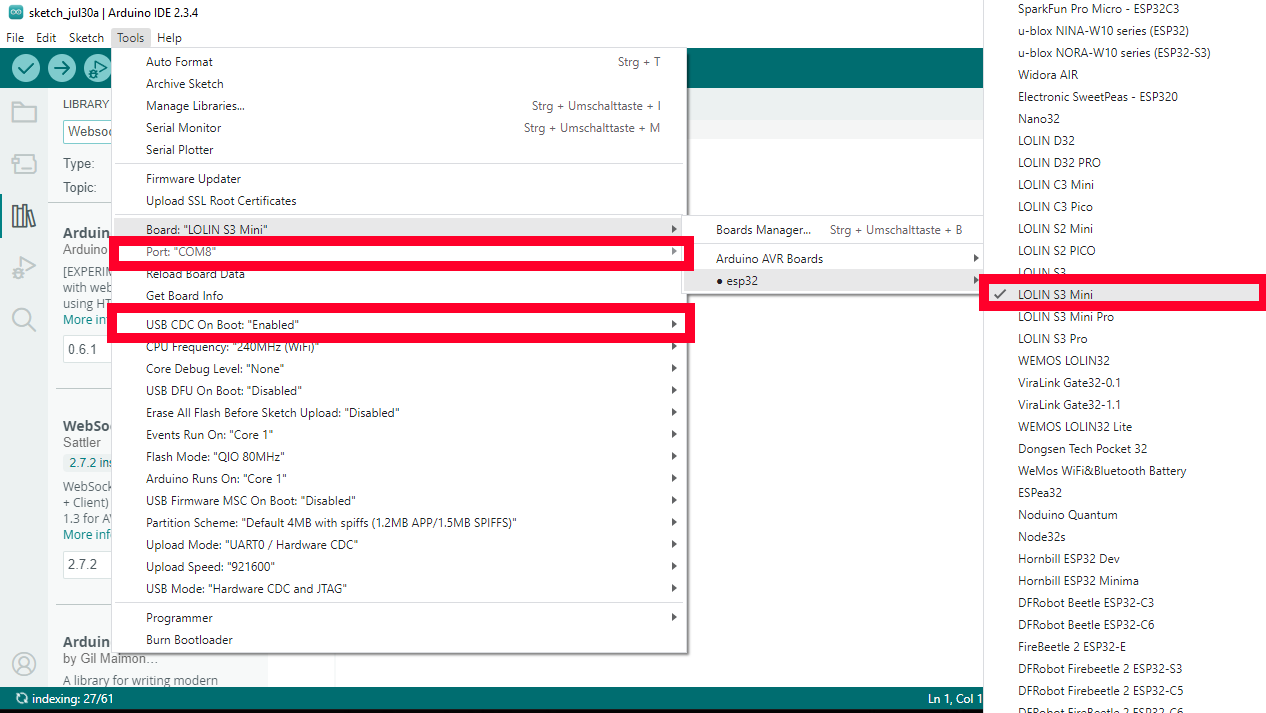
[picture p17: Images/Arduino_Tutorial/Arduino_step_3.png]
Arduino step 3


4. Copy one of the source code of the examples and click on compile and upload botton.
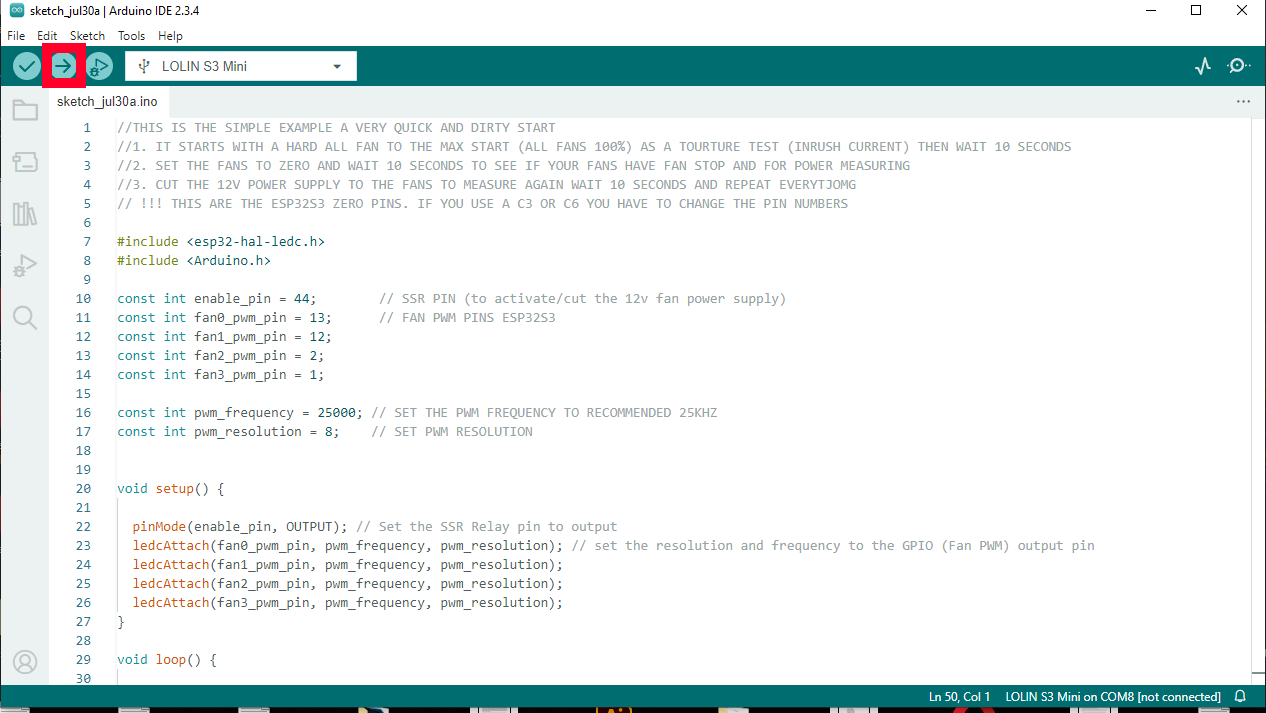
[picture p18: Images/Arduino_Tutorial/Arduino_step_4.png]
Arduino step 4


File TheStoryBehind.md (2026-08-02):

### The Story Behind the Board

It all started during an extremely hot summer when I desperately needed a fan. While standard fans were fine during the day, the nights were a different story. I am highly sensitive to noise, and the constant humming made it impossible to sleep. I happened to have four spare Noctua fans lying around, which are famous for their whisper-quiet operation and precise speed control.

At the time, I was heavily experimenting with Arduinos and had only just begun exploring the ESP32. Knowing that the fans required a 5V PWM signal and that the Arduino operated on a 5V logic level, I simply hooked it up. It worked even though, looking back, I probably wasn't hitting the exact required PWM frequency out of that Arduino. But it worked anyways<br>
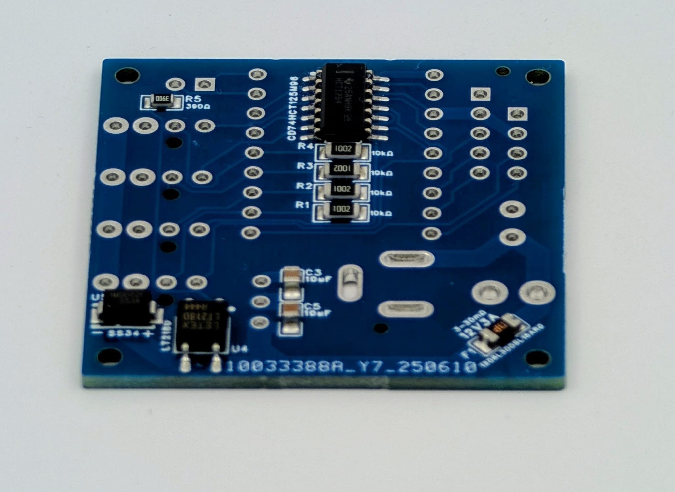
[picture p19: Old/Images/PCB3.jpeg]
First PCB image 3


### The Catalyst: 3D Printing

Fast forward a few years. Noctua released their Airflow Amplifier (NV-AA1-12) and generously provided the 3D files online. This instantly brought my old summer project back into focus. I took the files, scaled the model up to fit my 140mm fan, and printed it.

However, I was not a fan of the original control setup, which required a external box sitting on my desk. I wanted an elegant, integrated solution.<br>
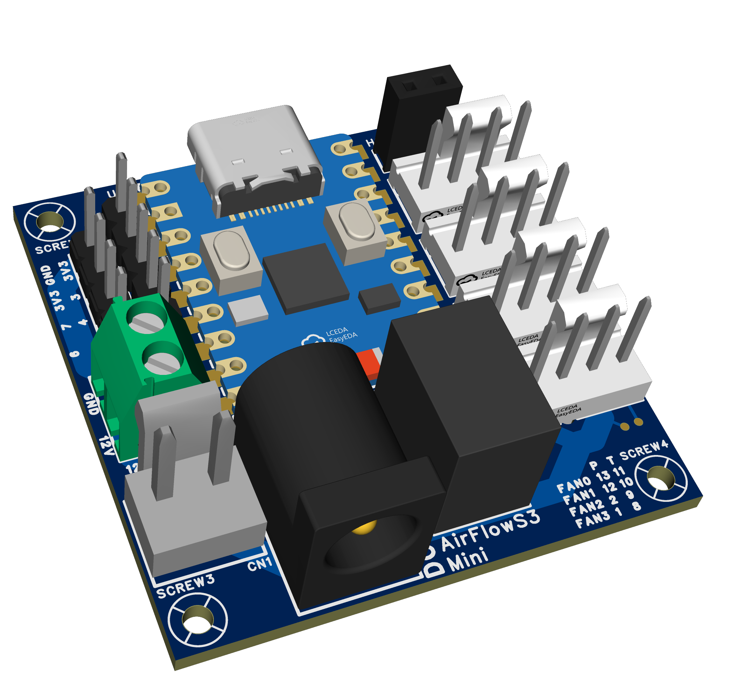
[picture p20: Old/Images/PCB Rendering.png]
First PCB Rendering


### The First Custom PCB

I set out to design a custom circuit board small enough to fit perfectly into the center hub of the 3D-printed airflow amplifier. My vision was ambitious:

* Direct control via a physical rotary knob right on the device.
* Smart connectivity to control the fan via smartphone.
* Maximum flexibility regarding power supply options.
* Ultra-low power dissipation. After all, the goal was to cool the room, not to generate unnecessary extra heat through inefficient voltage converters.

This became the very first custom PCB I ever designed. I placed the order, and when the boards finally arrived, I quickly realized there were two major design flaws. Fortunately, I managed to get them running for my own use with a few creative workarounds.<br>
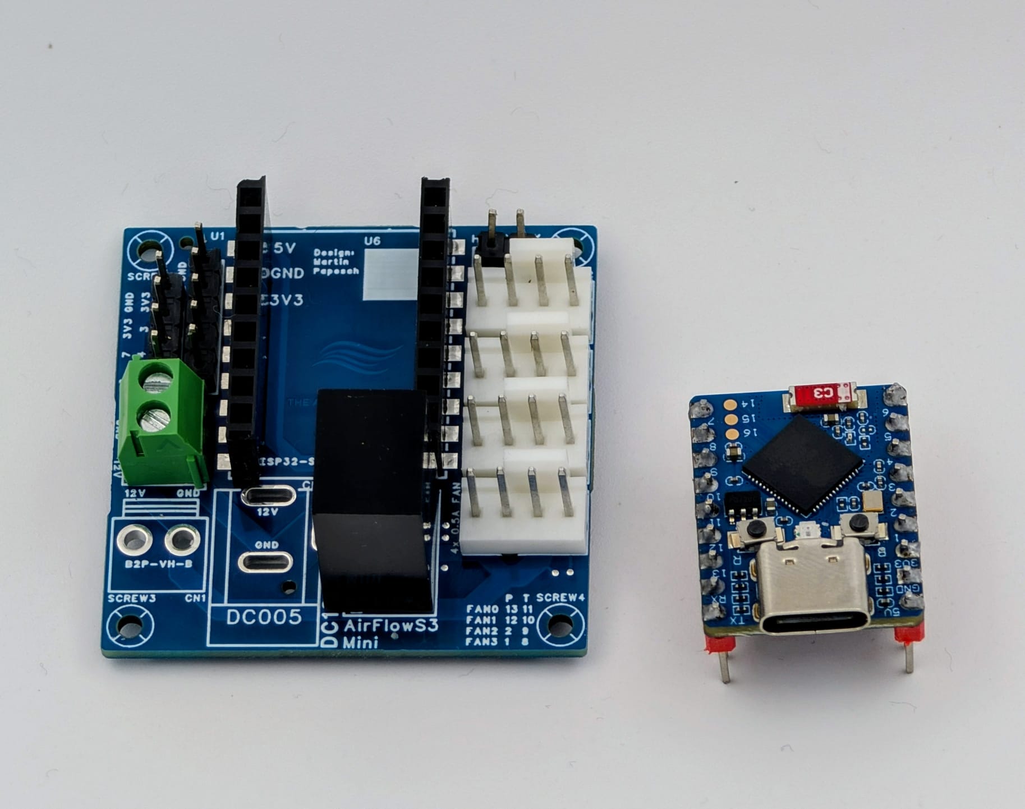
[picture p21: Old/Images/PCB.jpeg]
First PCB image


### Evolution and Refinement

That first board sparked a steep learning curve. Over time, I kept iterating on the design, learning new things, and adding more functionality. The board grew in complexity, and features kept being added until quite literally every single millimeter of PCB space was utilized.

Today, this project has evolved into an extremely dense PCB that finally meets every single one of my initial requirements. It has been an incredible learning journey, and I am just thrilled to finally share the result with the community, hoping others will find it just as useful for their own setups.

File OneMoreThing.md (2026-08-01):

# One More Thing...

Every carefully routed trace on this compact hub was designed with a single, primary goal in mind: mastering thermals. It orchestrates signals, tames the heat, and keeps the breeze flowing exactly as intended.

But hardware is only as rigid as the firmware that drives it. 

Hidden within the core of this controller lies an alternative path. If you are willing to strip away the fans, push a new payload, and completely reassign its purpose, the logic of cooling gives way to a completely different spectrum. 

*If the airflow settles, there could be room for something brighter.*

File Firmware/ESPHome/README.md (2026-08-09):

# HomeAssistant Tutorial


**1** Go to you HomeAssistant. Open the "SETTINGS" and click on "APPS".<br>
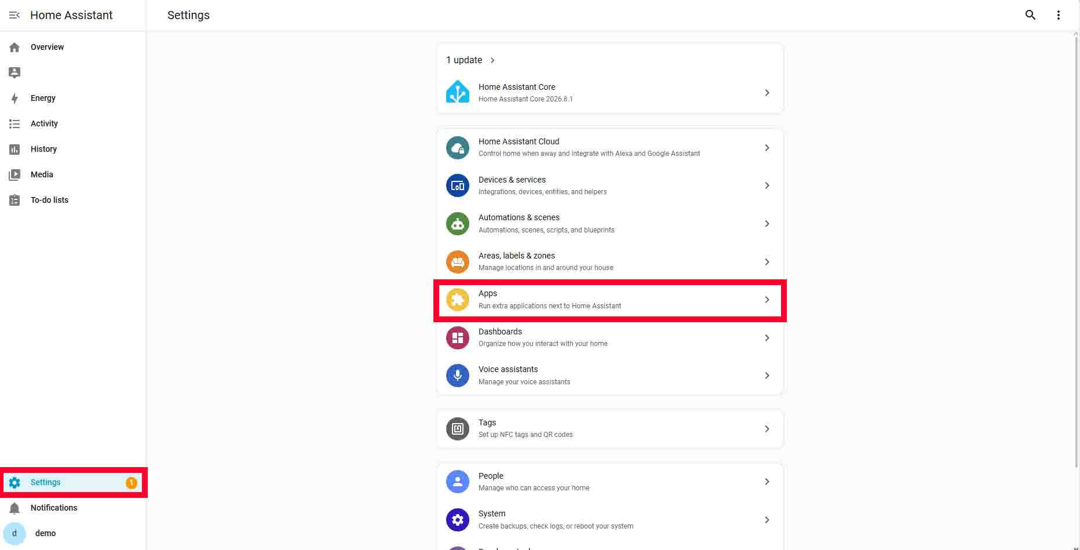
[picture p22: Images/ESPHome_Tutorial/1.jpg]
ESPHome step 1
<br><br>

**2** Click on "You dont have any apps installed yet..."<br>
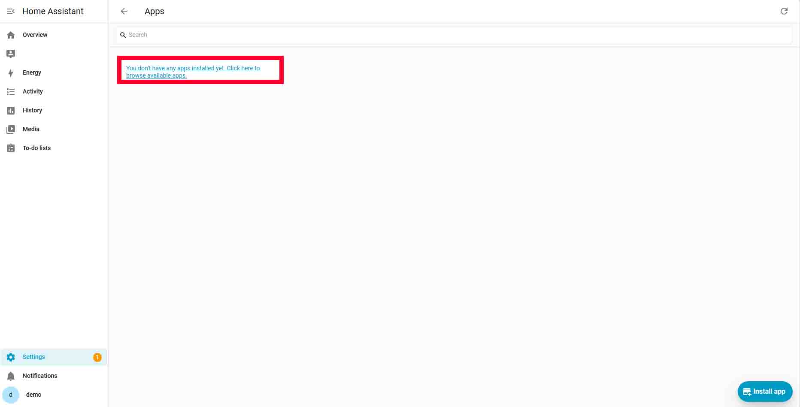
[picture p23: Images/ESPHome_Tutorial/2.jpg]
ESPHome step 2
<br><br>

**3** Type in "ESPHome" and click (install) the "ESPHome device builder"<br>
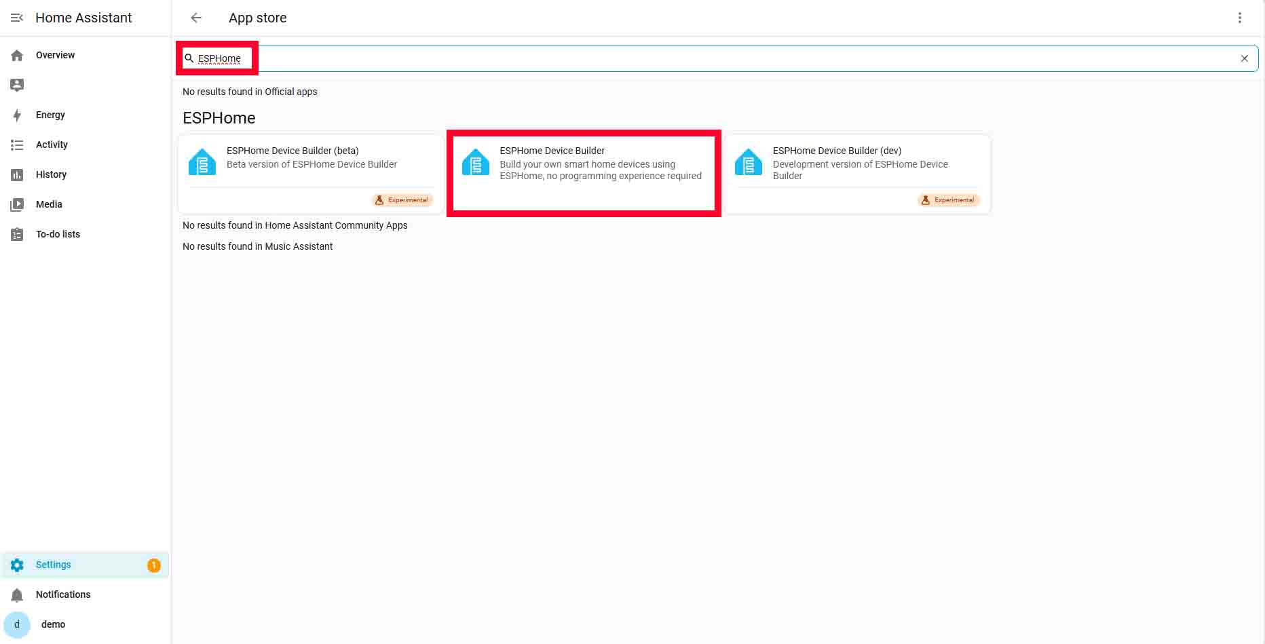
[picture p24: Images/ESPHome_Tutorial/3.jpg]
ESPHome step 3
<br><br>

**4** Install ESPHome by clicking the Botton <br>
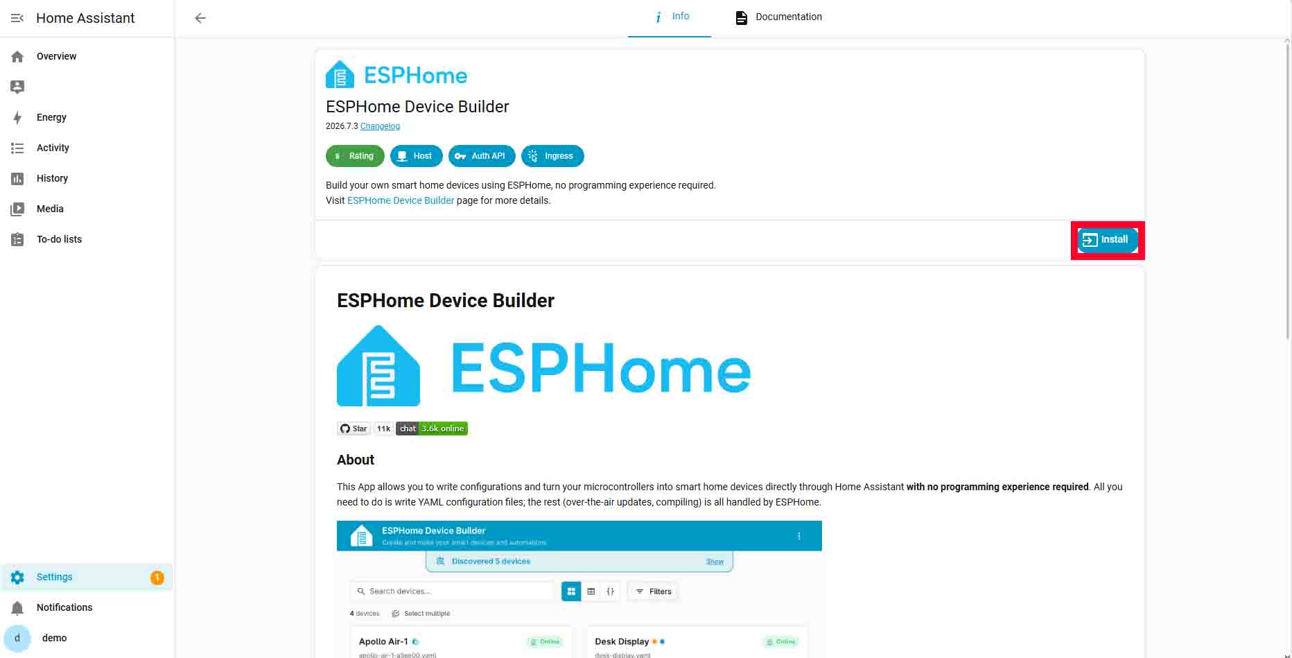
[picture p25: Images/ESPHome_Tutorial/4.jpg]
ESPHome step 4
<br><br>

**5** Start the ESOHome by clicking "START"<br>
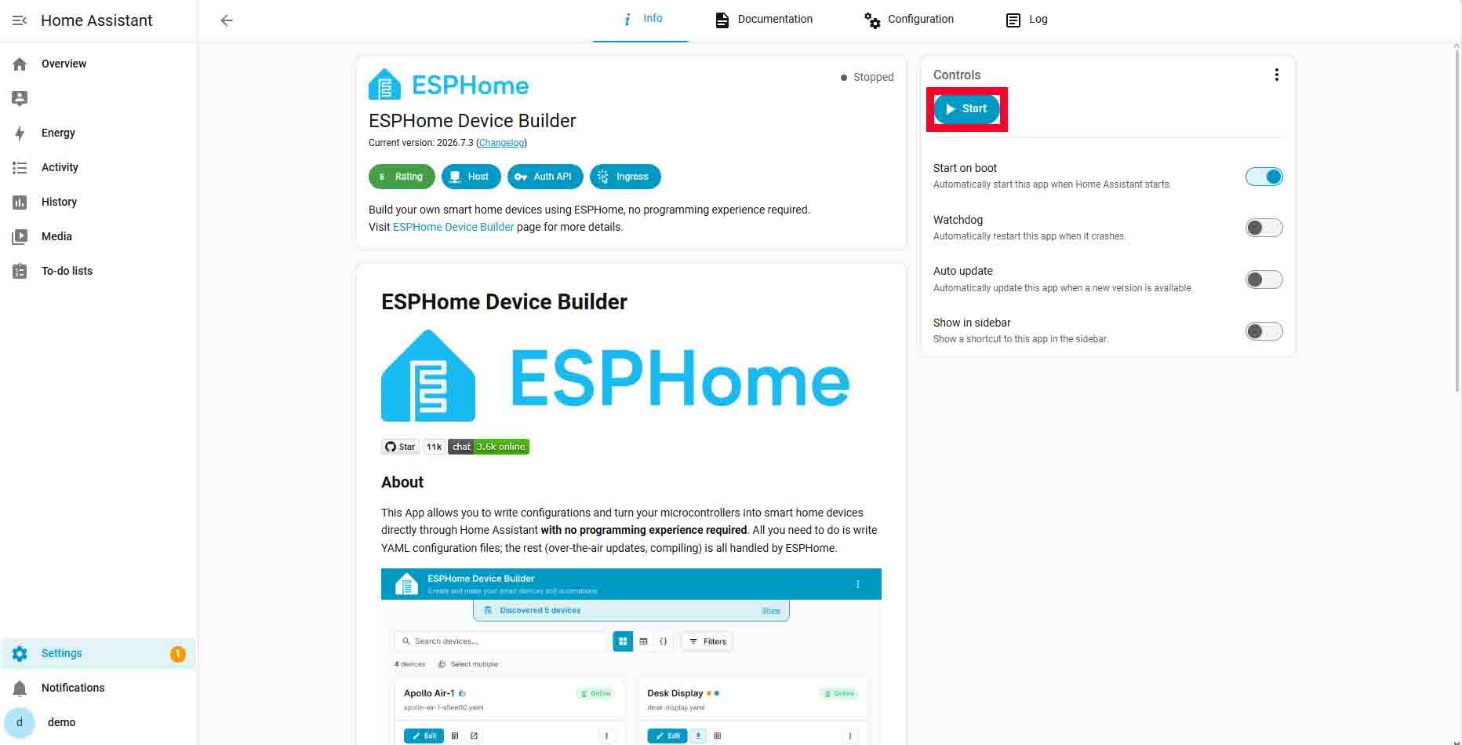
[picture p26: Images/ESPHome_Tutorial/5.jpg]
ESPHome step 5
<br><br>

**6** Click "OPEN WEB UI"<br>
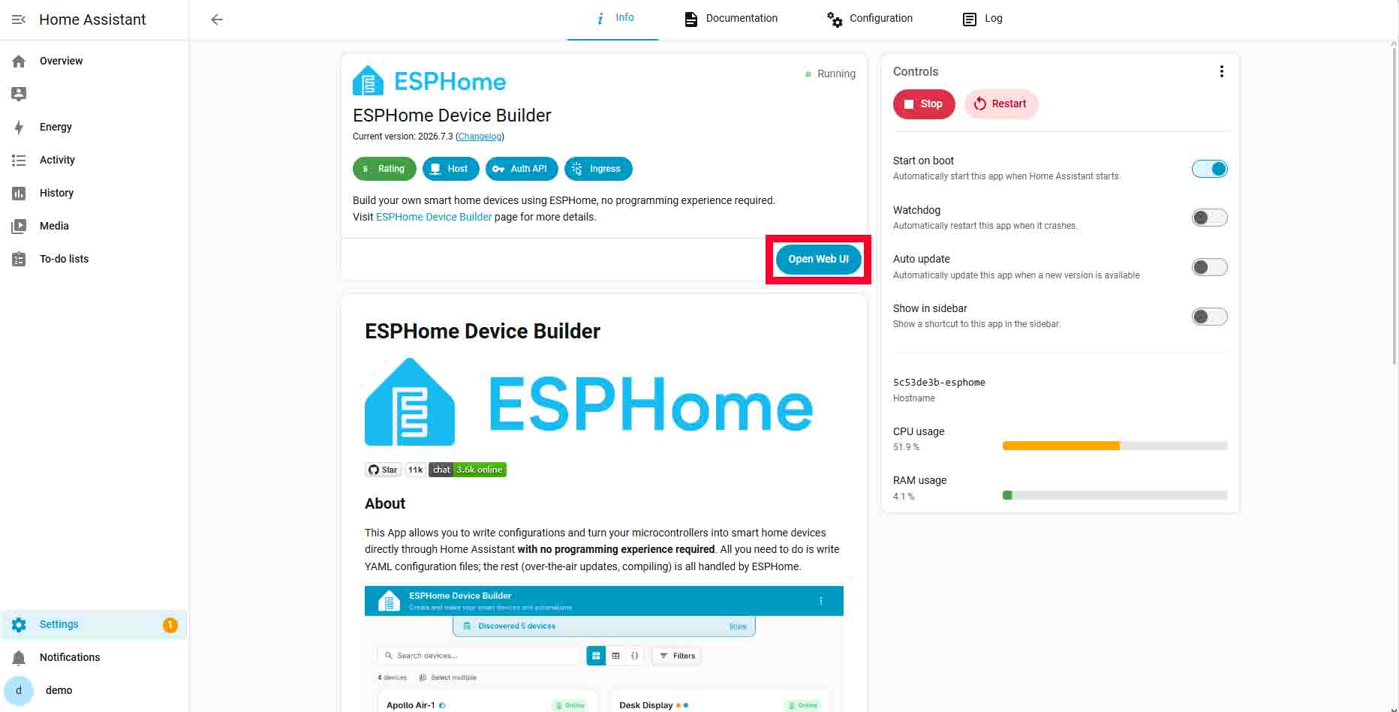
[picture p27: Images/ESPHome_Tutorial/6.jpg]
ESPHome step 6
<br><br>

**7** Add a new Device by clicking the "+" Icon<br>
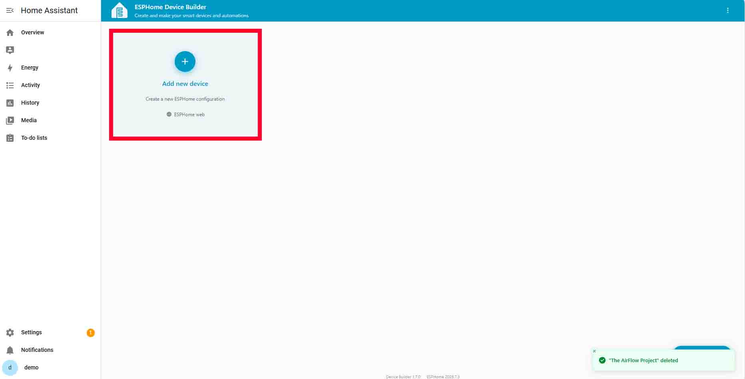
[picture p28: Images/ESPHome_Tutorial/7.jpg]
ESPHome step 7
<br><br>

**8** Open the "ADVANCED SETUP OPTION" and click on "EMPTY CONFIGURATION"<br>
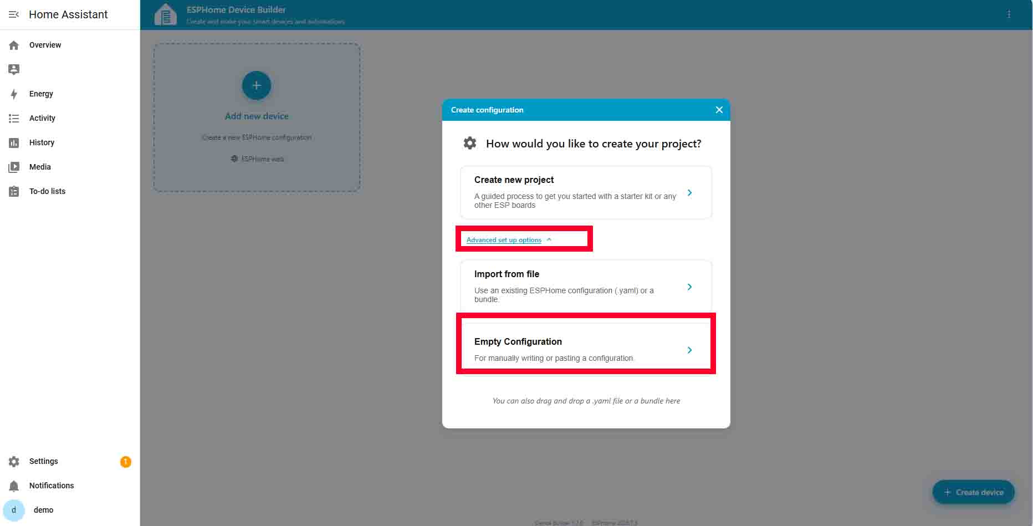
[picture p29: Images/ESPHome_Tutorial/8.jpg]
ESPHome step 8
<br><br>

**9** Put in any name it does not matter because that will be overwritten later. Continue by clicking "FINISH SETUP"<br>
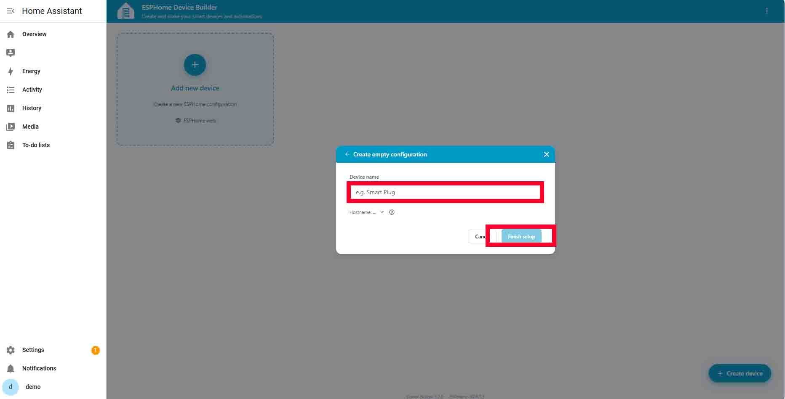
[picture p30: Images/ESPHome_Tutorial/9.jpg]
ESPHome step 9
<br><br>

**10** Open the Yaml file here on Github in a new tab and copy that to the clipboard by clicking the "COPY"<br>
<br>
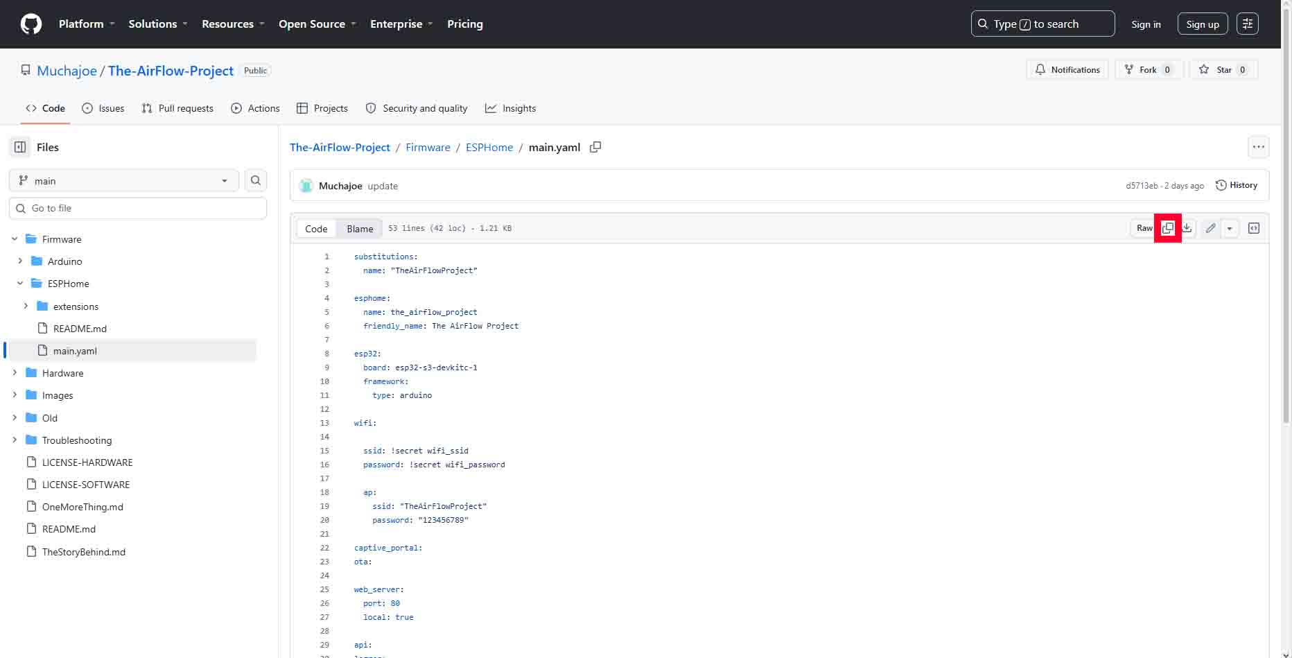
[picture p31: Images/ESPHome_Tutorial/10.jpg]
ESPHome step 10
<br><br>

**11** Go back to the configuration. Select and delete the whole text<br>
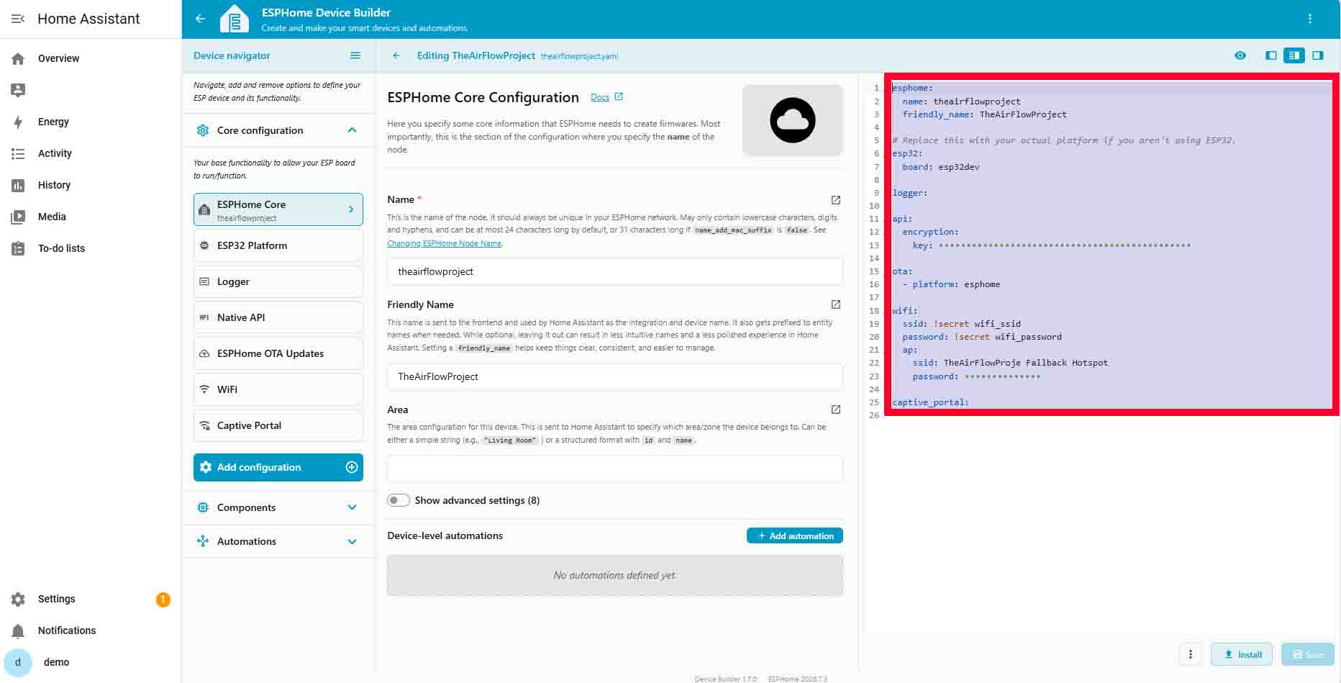
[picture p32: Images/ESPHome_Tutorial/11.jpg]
ESPHome step 11
<br><br>

**12** Paste the copied text from yout clipboard bei right click and choose paste (or STRG+V or CMD+V)<br>
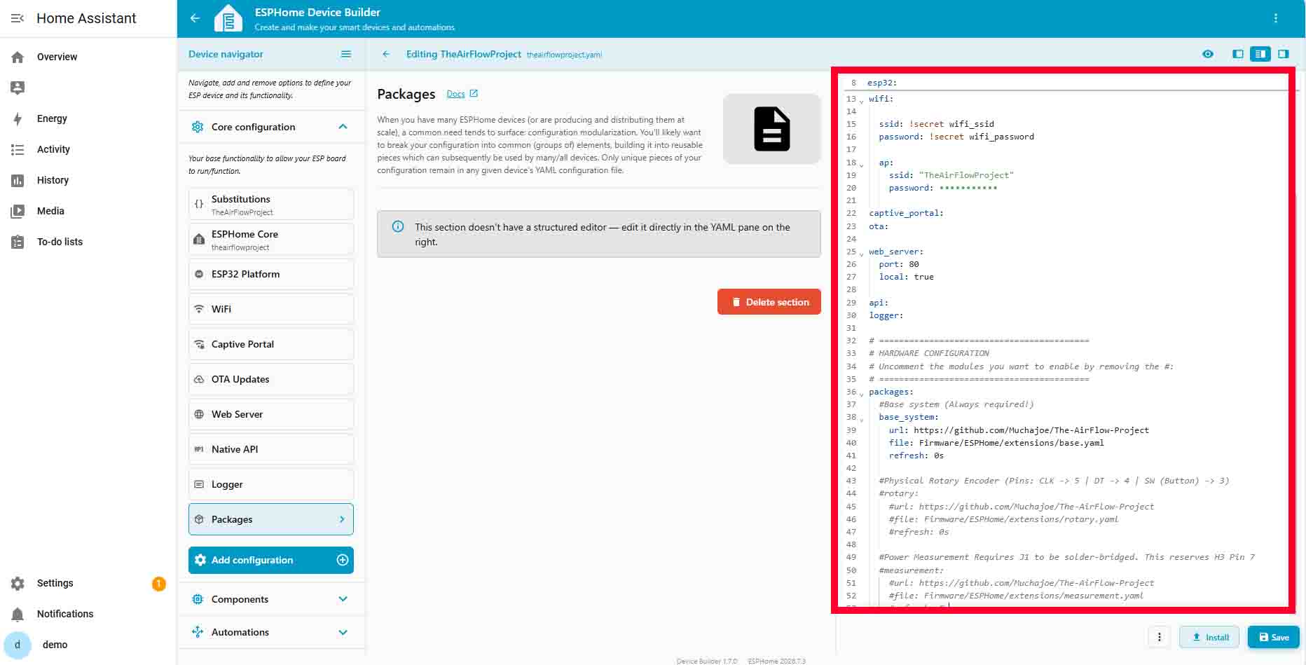
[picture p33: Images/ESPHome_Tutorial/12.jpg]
ESPHome step 12
<br><br>

**13** Gp to WIFI and put in your WIFI Credentials<br>
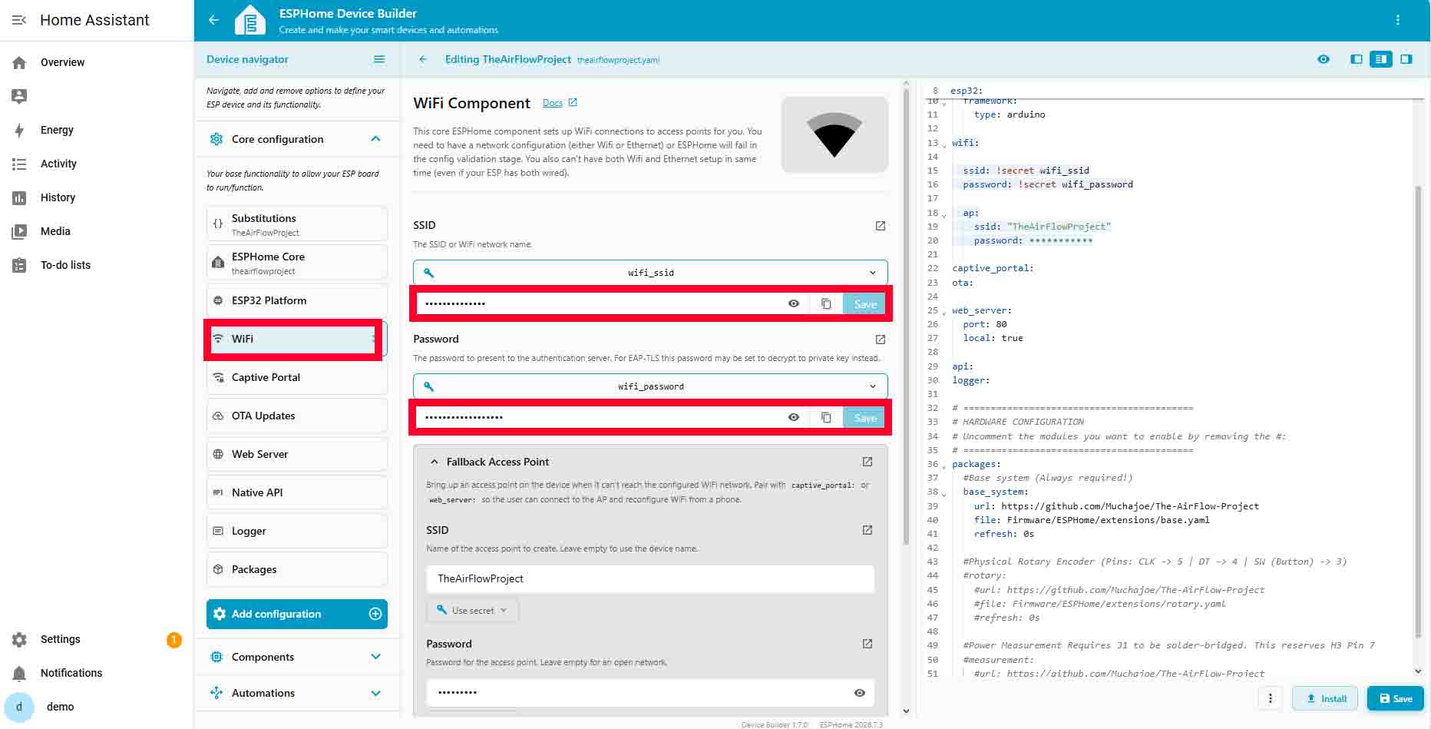
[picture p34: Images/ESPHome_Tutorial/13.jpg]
ESPHome step 13
<br><br>

**14** Click on SAVE (right bottom corner). Then click install and Choose "PLUG INTO THIS COMPUTER" **THIS MAY TAKE UP TO 20 MINUTES**<br>
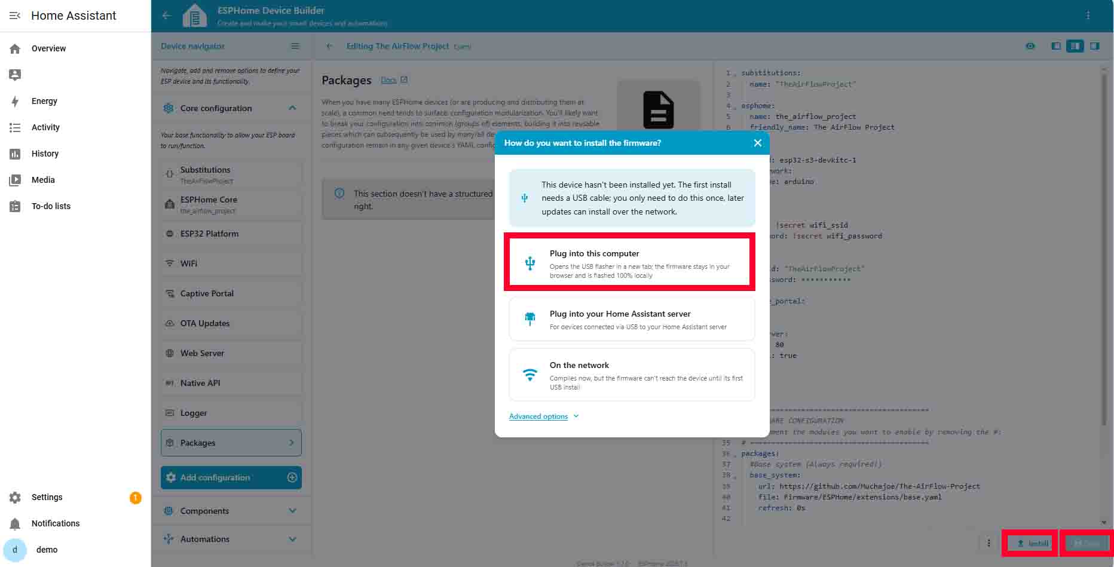
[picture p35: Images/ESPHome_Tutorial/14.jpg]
ESPHome step 14
<br><br>

**15** "OPEN USB FLASHER"<br>
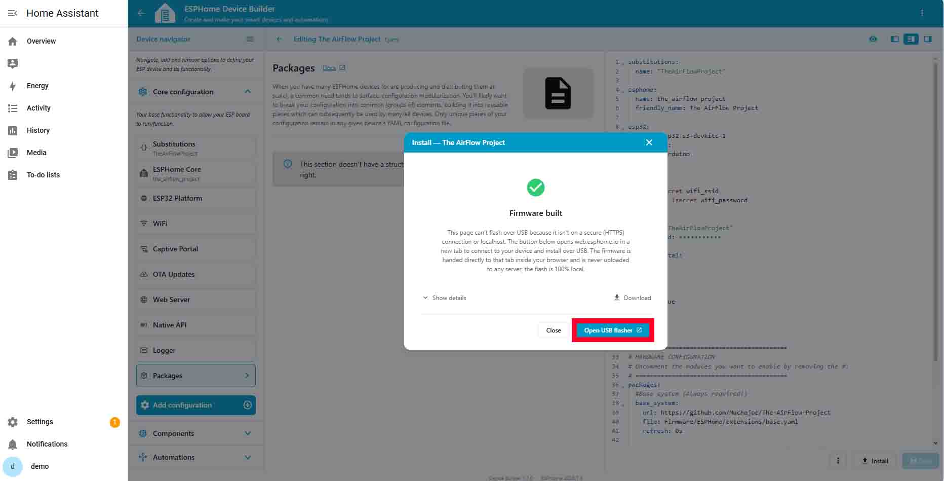
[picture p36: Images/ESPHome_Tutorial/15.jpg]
ESPHome step 15
<br><br>

**16** Choose "CONNECT AND INSTALL"<br>
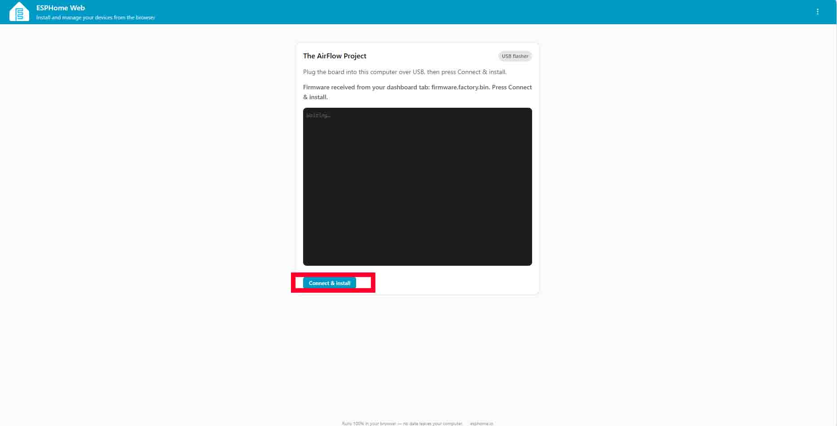
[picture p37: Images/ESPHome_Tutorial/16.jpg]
ESPHome step 16
<br><br>

**17** Search for your USB COM Port. Usually there is only one in the list. And click on "CONNECT" **THIS MAY TAKE SOME TIME TOO.** If there opens a (LOG) window, you can close this tab and go back to your HomeAssistant<br>
ESPHome step 17<br><br>

**18** Go to "OVERVIEW" and click on "DEVICES DISCOVERED"<br>
ESPHome step 18<br><br>

**19** You should find **The Airflow Project** in the List. Click on it.<br>
ESPHome step 19<br><br>

**20** On "DEVICES" you should find the controls<br>
ESPHome step 20<br><br>

**21** DONE. Now you can assign **The AirFlow Project** to any area you want <br>
ESPHome step 21<br><br>

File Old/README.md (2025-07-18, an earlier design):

# The-AirFlow-Project

The AirFlowS3 mini is a compact and versatile control board specifically designed for precise control of up to four 12V fans using PWM. Featuring an ESP32S3 zero microcontroller, it offers flexible control options via an intuitive web user interface or a rotary encoder. A key feature is the integrated complete disconnection of the 12V supply to the fans at 0% PWM, implemented via a Solid State Relay (SSR), to save energy and minimize noise when the fans are not needed.

Features & Highlights
Four PWM-Controlled 12V Fan Outputs: Enables precise control over fan speed.

Intelligent 12V Shutdown: At 0% PWM, the 12V supply to the fans is completely disconnected via an LT218D SSR including a 390 Ohm series resistor.

RPM Signal Detection: Each fan connector (4-pin FAN Header) includes a 10 kOhm pull-up resistor for detecting the RPM signal.

PWM Level Shifting: A CD74HCT125M96 ensures correct PWM signal level adaptation.

Flexible Control:

Web User Interface: Allows for convenient configuration and control over a network.

Rotary Encoder: A dedicated 5-pin header enables direct connection of a rotary encoder for manual control.

Expansion Possibilities: A 4-pin header is available for connecting additional accessories, such as temperature sensors.

Efficient Power Supply:

K7805-1000R3 Fixed Voltage Regulator: Provides a stable 5V supply for the ESP32S3 zero.

Versatile 12V Input Options: The board can be powered by 12V via a DC005 jack, KF350-3.5-2P terminals, or B2P-VH-B(LF)(SN) connector.

Safety Features: A 1206L300SL16ARG fuse and an SS34 flyback diode protect the circuitry.

Extremely Compact Design: Measuring only 40mm x 40mm, the AirFlowS3 mini is ideal for projects with limited space.

Cost-Optimized: The design avoids vias to keep manufacturing costs low.

Mounting: Hole spacing of 35.4mm with 2mm diameter for easy mounting.

Use Cases
The AirFlowS3 mini is perfect for projects requiring intelligent and efficient fan control, such as:

PC Case Fan Control

3D Printer Cooling

Small Server Racks or Enclosures

Home Automation Projects

Cooling Modules for Electronic Devices

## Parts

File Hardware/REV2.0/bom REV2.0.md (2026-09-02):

# REV 2.0 <br><br>

| No. | Quantity| Comment| Designator|Footprint | Value| Typ| Supplier Part| Supplier|
| --- |:---:|:---:|:---:|:---:|:---:|:---:|:---:|:---:|
|1|3|10uF|C1,C2,C3|C0805|10uF||SMD|C15850|LCSC|
|2|1|100nF|C4|C0805|100nF||SMD|C2168659|LCSC|
|3|5|10k|R1,R2,R3,R4,R5|R0805|10k||SMD|C2930231|LCSC|
|4|1|330|R7|R0805|330||SMD|C17630|LCSC|
|5|1|4.7k|R8|R0805|4.7k||SMD|C2907264|LCSC|
|6|4|62|R9,R11,R12,R13|R0805|62||SMD|C2933559|LCSC|
|7|1|1k|R10|R0805|1k||SMD|C2907295|LCSC|
|8|1|BZT52C15|D5|SOD-123_L2.6-W1.7-LS3.5-RD|BZT52C15||SMD|C54930262|LCSC|
|9|1|SMF15A|D6|SOD-123_L2.7-W1.8-LS3.7-RD|SMF15A||SMD|C435484|LCSC|
|10|1|SS34|D7|SMA_L4.2-W2.7-LS5.0-RD|SS34||SMD|C5200641|LCSC|
|11|4|1N5819W|D1,D2,D3,D4|SOD-123_L2.7-W1.6-LS3.7-RD|1N5819W||SMD|C41431973|LCSC|
| - |-|-|-|-|-|-|-|-|
|12|1|1206L300SL16ARG|F1|L1206|1206L300SL16ARG||SMD|C28326707|LCSC|
|13|1|AO4407A|Q1|SOP-8_L4.9-W3.9-P1.27-LS6.0-BL|AO4407A||SMD|C7379957|LCSC|
|14|1|ESP32-S3-Zero|U1||ESP32-S3-Zero||THT|||
|15|1|CD74HCT125M96|U2|SOIC-14_L8.7-W3.9-P1.27-LS6.0-BL|CD74HCT125M96||SMD|C133797|LCSC|
|16|1|K7805-1000R3|U3|PWRM-TH_K78XX-1000R3|K7805-1000R3||THT|C5378004|LCSC|
|17|1|TPS1H100BQPWPRQ1|U7|PDSO-G14_L5.0-W4.4-P0.65-LS6.4-BL-EP|TPS1H100BQPWPRQ1||SMD|C475505|LCSC|
| - |-|-|-|-|-|-|-|-|
|18|4|Molex Fan Header|FAN0,FAN1,FAN2,FAN3|CONN-TH_4P-P2.54_0470531000|470531000||THT|C3025061|LCSC|
|19|2|HDR-F_2.54_1x9P|H5,H6|HDR-TH_9P-P2.54-V-F|||THT|||
|20|1|HDR-F_2.54_1x2P|H2|HDR-TH_2P-P2.54-V-F|||THT|||
|21|1|HDR-M_2.54_1x4P|H3|HDR-TH_4P-P2.54-V-M|||THT|||
|22|1|HDR-M_2.54_1x6P|H4|HDR-TH_6P-P2.54-V-M|||THT|||
| - |-|-|-|-|-|-|-|-|
|~~23~~|~~1~~|~~DC005~~|~~CN2~~|~~DC-IN-TH_DC005~~|~~DC005~~|REPLACED to 23.1|~~THT~~|~~C431533~~|~~LCSC~~|
|23.1|1|PJ-002AH|CN2|DC-IN-PJ-002AH|PJ-002AH||THT|C2961147|LCSC|
|24|1|KF350-3.5-2P|CN3|CONN-TH_P3.50_KF350-3.5-2P|KF350-3.5-2P|optional|THT|C474892|LCSC|
|25|1|B2P-VH-B(LF)(SN)|CN1|CONN-TH_B2P-VH-B-LF-SN|B2P-VH-B(LF)(SN)|optional|THT|C265114|LCSC|

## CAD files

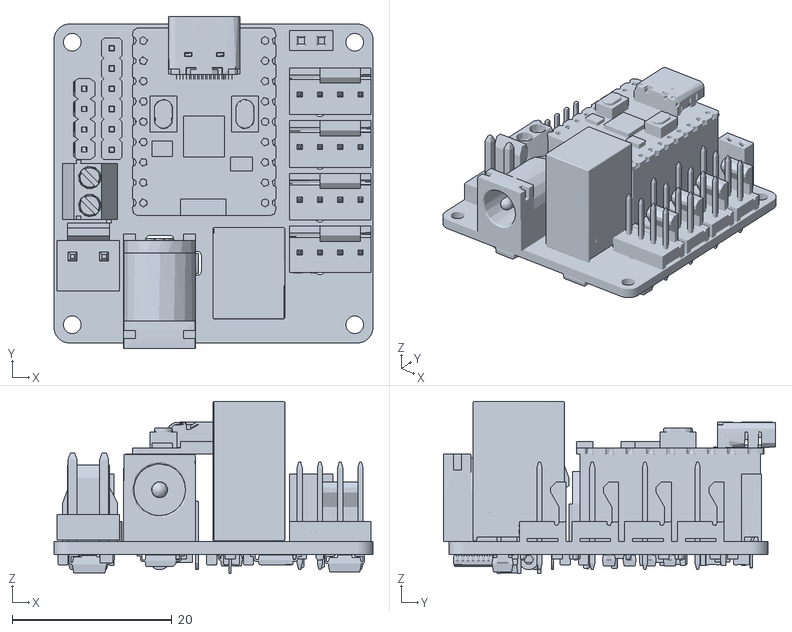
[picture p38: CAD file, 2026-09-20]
Hardware/REV2.0/pcb REV2.0.stl
40.0 x 41.7 x 21.6

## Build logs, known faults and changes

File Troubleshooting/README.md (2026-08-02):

# Troubleshooting

you need a multimeter and your 12v Power supply. Take a look in the Pictures in this folder to find the measuring points. 

1. **Continuity test**
disconnect your power supply and set your multimeter to continuity test mode. One of your measuring tip stays on the red pont. With the other tip you go from one to another of the blue measuring points. It should have continuity.

[Get the measuring points (Continuity test)](/Troubleshooting/continuity_test.png)<br>
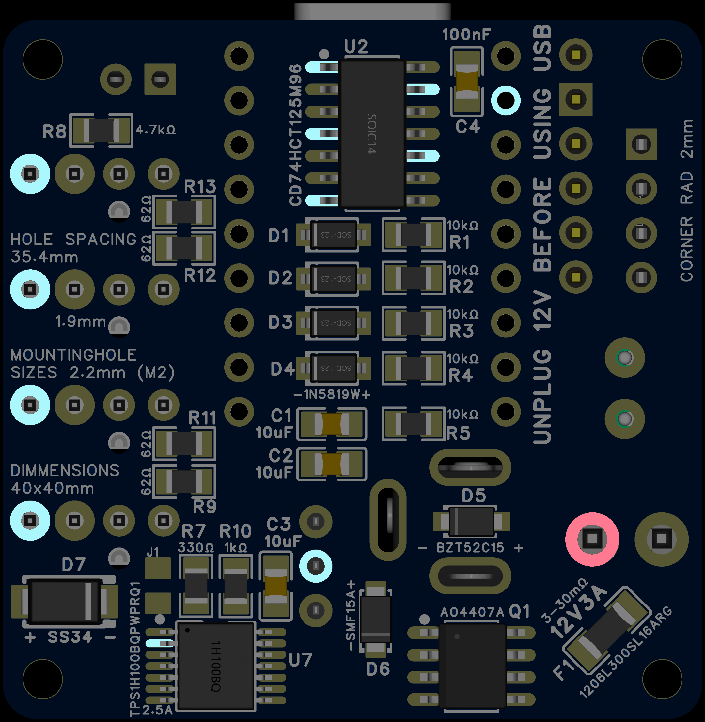
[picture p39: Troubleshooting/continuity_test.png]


2. **Voltage test** (do it only if you know what you are doing here)
Set your multimeter to DC voltage test. Connect your 12v Power suply to your PCB. One of your measuring tip stays on the red point. With the other tip you go from one to another of the blue measuring points.

[Get the measuring points (Voltage test)](/Troubleshooting/voltage_test.png)<br>
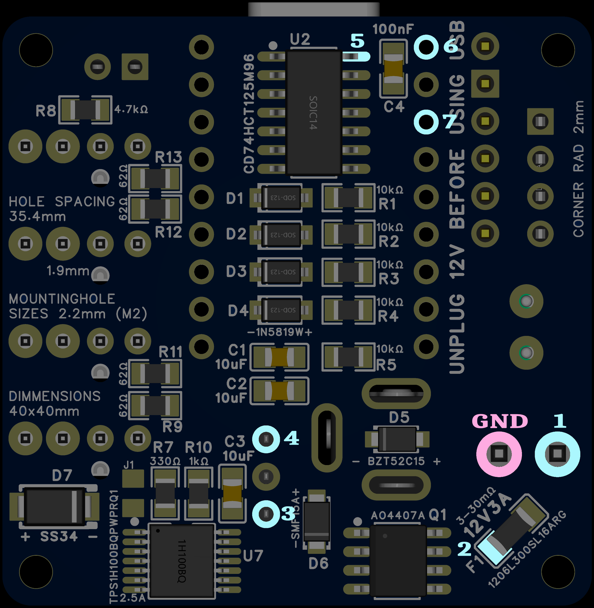
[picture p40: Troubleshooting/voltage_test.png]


| Point 1 | Point 2| Expected value| Possible failure|
| --- |:---:|:---:|:---:|
| GND | 1 |12v |Probelm with your power supply|
| GND | 2 |12v |Problem with your fuse F1|
| GND | 3 |12v |Problem with Q1 (reverse polarity protection p-channel mosfet)|
| GND | 4 |5v|Problem with your voltage regulator U3|
| GND | 5 |5v|Problem with the pcb trace|
| GND | 6 |5v|Problem with the pcb trace|
| GND | 7 |3.3v|Problem with your ESP32 voltage regulator|

3. **Efuse Test**
Set your multimeter to DC voltage test. Connect your 12v Power suply to your PCB. Connect 3.3V (From H4 or H3) with a jumperWire to H2 PIN 44. That switches the Power supply for the Fans on. Than you can measure if the 12v reaches the FAN Connectors. You should have 12v on every blue point against the GND. 

[Connect the Enable pin to 3.3v (eFuse test)](/Troubleshooting/eFuse_test_1.png)<br>
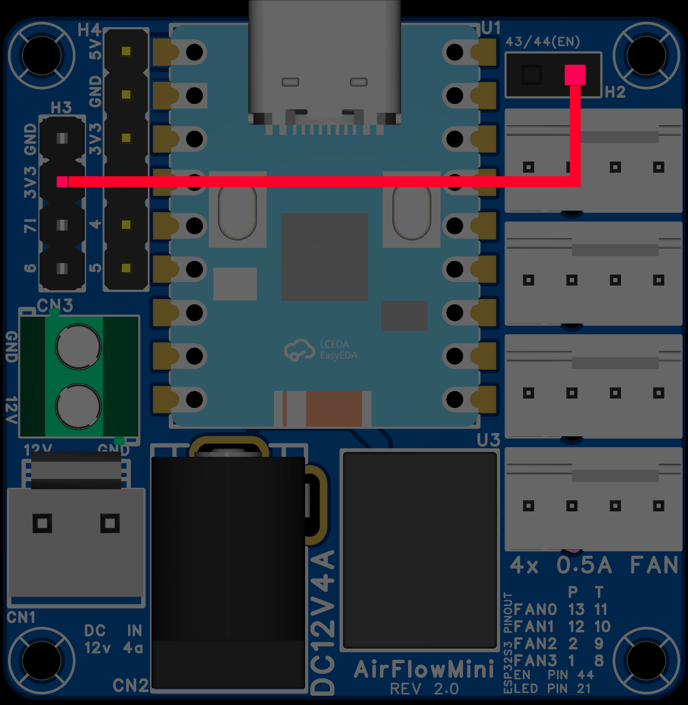
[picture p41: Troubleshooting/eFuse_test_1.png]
<br>

[Get the measuring points (eFuse test)](/Troubleshooting/eFuse_test_2.png)<br>
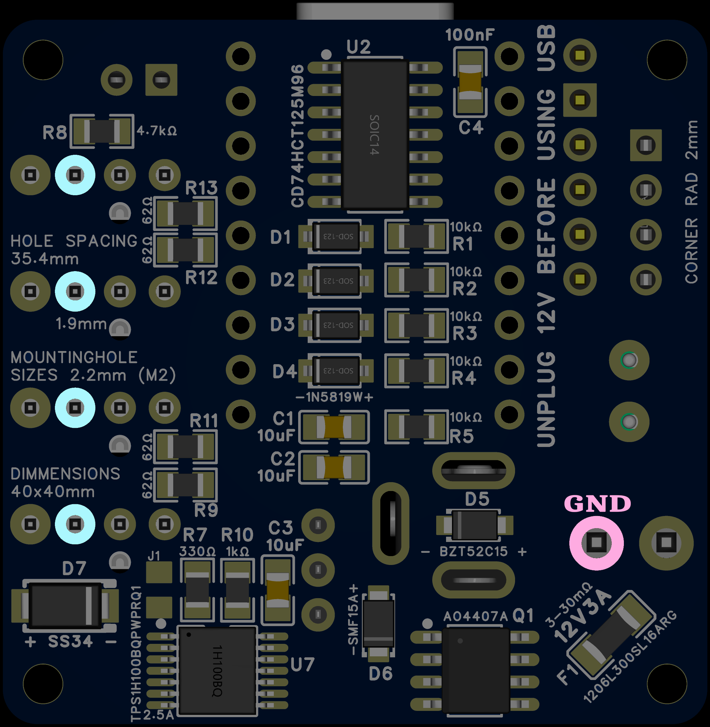
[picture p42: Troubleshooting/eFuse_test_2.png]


4. **Continous overvoltage Case** If you accidentally connected a 16-24V power supply, it is highly likely that only the D6 SMF15A diode has blown.

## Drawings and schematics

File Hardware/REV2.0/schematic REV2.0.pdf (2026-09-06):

### GND

SCREW1 | SCREW2 | SCREW3 | SCREW4 GND

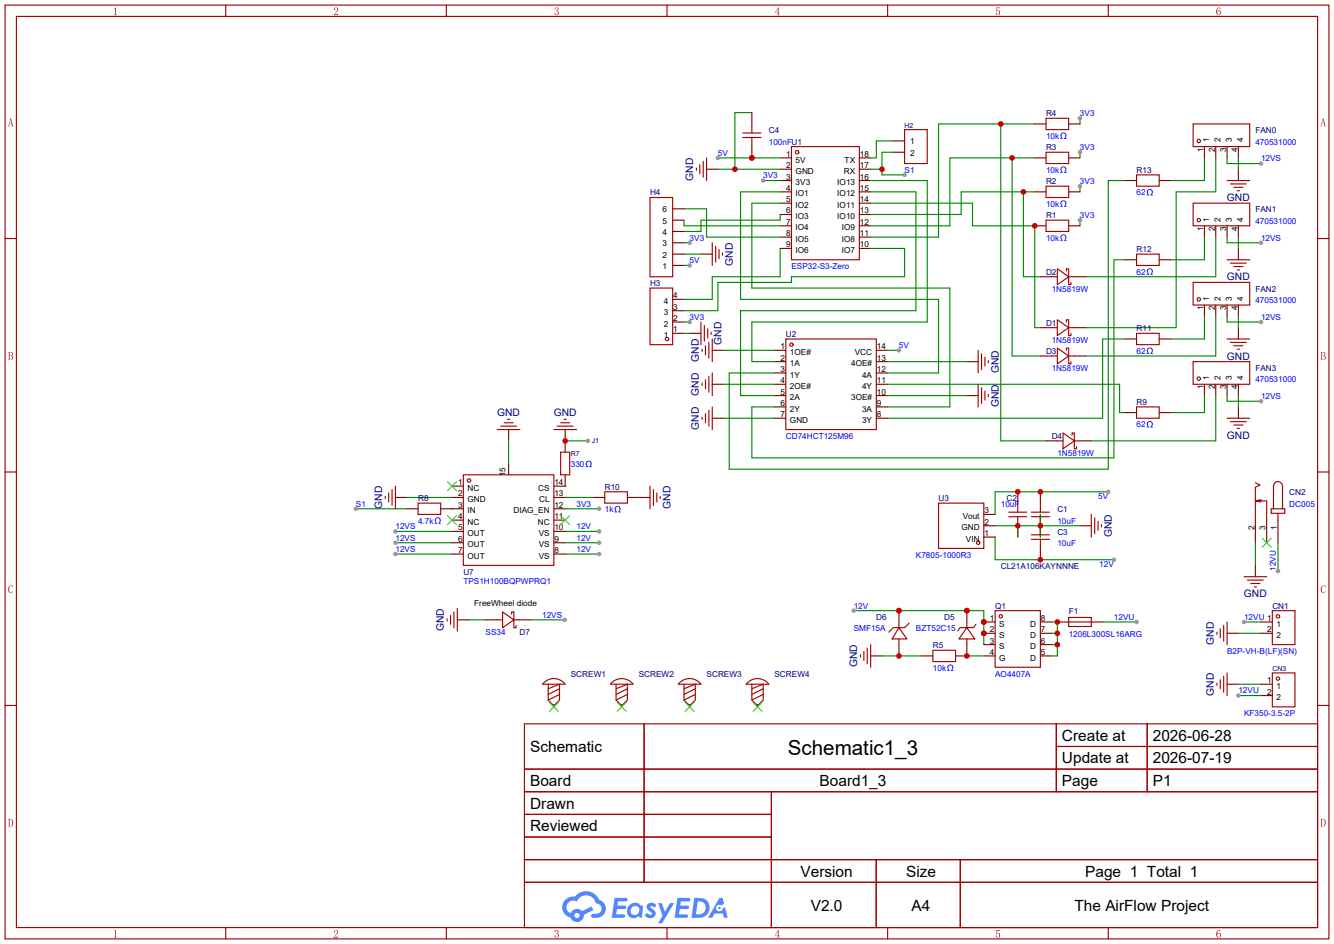
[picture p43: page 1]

Schematic | Schematic1_3 | Create at | 2026-06-28

Update at | 2026-07-19

Board | Board1_3 | Page | P1
Drawn
Reviewed

Version | Size | Page 1 Total 1
V2.0 | A4 | The AirFlow Project

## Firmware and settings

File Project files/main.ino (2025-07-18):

#include <ESP32Encoder.h>
#include <Adafruit_NeoPixel.h>
#include <driver/pcnt.h>
#include <esp32-hal-ledc.h>
#include <esp_system.h>
#include <rom/ets_sys.h>
#include <ArduinoJson.h>
#include <FS.h>
#include <LittleFS.h>

#include <WiFi.h>
#include <WebServer.h>
#include <WebSocketsServer.h>


//WIFI AP Mode, HTTP GET REQ API, WEB UI, LittleFS config save, WIFI STA Mode, WIFI Credentials

//PINS
int encoder_pin0 = 7; //3
int encoder_pin1 = 6; //4
int encoder_switch = 5;
int led_pin = 21;         // GPIO 21 for ESP32-S3 Zero
int num_leds = 1;         // 1 LED
int enable_pin = 44;      // GPIO SSR PIN (TX-Pin) if not working try io 43,14,15 or wire and use IO10
int fan0_pwm_pin = 13;
int fan0_rpm_pin = 11;
//int fan0_channel = 1;
pcnt_unit_t fan0_pcnt_unit = PCNT_UNIT_0;
int fan1_pwm_pin = 12;
int fan1_rpm_pin = 10;
//int fan1_channel = 2;
int fan2_pwm_pin = 2;
int fan2_rpm_pin = 9;
//int fan2_channel = 3;
int fan3_pwm_pin = 1;
int fan3_rpm_pin = 8;
//int fan3_channel = 4;

int pwm_frequency = 25000;
int pwm_resolution = 8;

ESP32Encoder encoder;
Adafruit_NeoPixel led(num_leds, led_pin, NEO_GRB + NEO_KHZ800);

int fan0_pwm = 0;
int16_t fan0_rpm = 0;
bool fan_0 = true;

int fan1_pwm = 0;
int16_t fan1_rpm = 0;
bool fan_1 = true;

int fan2_pwm = 0;
int16_t fan2_rpm = 0;
bool fan_2 = true;

int fan3_pwm = 0;
int16_t fan3_rpm = 0;
bool fan_3 = true;

int mode = 4; // Mode counter
int value = 0;
int64_t pos = 0;

int old_encoder_value = 102;
int new_encoder_value;

String ap_password = "123456789";
String ap_ssid = "AirFlow";
String ap_ip;
String sta_password;
String sta_ssid;
String sta_ip;

unsigned long lastTime;

WebServer server(80);
WebSocketsServer webSocket = WebSocketsServer(81);

const int wdtTimeout = 6000;  // Watchdog time in ms to trigger the watchdog
hw_timer_t *timer = NULL;     // Watchdog

void webRoutes();
void sendLiveDataWS();
void init_pcnt();

void ARDUINO_ISR_ATTR resetModule() { // Watchdog
  ets_printf("reboot\n");
  esp_restart();
}

void setup() {
  Serial.begin(9600);

  timer = timerBegin(1000000);                     // Watchdog timer 1Mhz resolution
  timerAttachInterrupt(timer, &resetModule);       // Watchdog attach callback
  timerAlarm(timer, wdtTimeout * 1000, false, 0);  // Watchdog set time in us

  if (!LittleFS.begin()) {
    Serial.println("Failed to start LittleFS");
    return;
  }

  pinMode(enable_pin, OUTPUT);
  ledcAttach(fan0_pwm_pin, pwm_frequency, pwm_resolution);
  ledcAttach(fan1_pwm_pin, pwm_frequency, pwm_resolution);
  ledcAttach(fan2_pwm_pin, pwm_frequency, pwm_resolution);
  ledcAttach(fan3_pwm_pin, pwm_frequency, pwm_resolution);

  WiFi.softAP(ap_ssid, ap_password);
  webRoutes();
  server.begin();
  init_pcnt();

  encoder.attachHalfQuad(encoder_pin0, encoder_pin1);
  encoder.setCount(50);
}

void loop() {
  timerWrite(timer, 0);  //reset timer (feed watchdog)
  unsigned long currentTime = millis();

  pos = encoder.getCount();
  new_encoder_value = pos;
  if (new_encoder_value != old_encoder_value){
    value = new_encoder_value;
    old_encoder_value = new_encoder_value;
    mode = 4;
    }


  if (currentTime - lastTime >= 2000) {  // intervall 30000
      lastTime = currentTime;

  pcnt_counter_pause(PCNT_UNIT_1);
  //pcnt_counter_pause(PCNT_UNIT_2);
  //pcnt_counter_pause(PCNT_UNIT_3);
  pcnt_get_counter_value(PCNT_UNIT_1, &fan0_rpm);
  //pcnt_get_counter_value(PCNT_UNIT_2, &fan1_rpm);
  //pcnt_get_counter_value(PCNT_UNIT_3, &fan2_rpm);
  pcnt_counter_clear(PCNT_UNIT_1);
    //pcnt_counter_clear(PCNT_UNIT_2);
    //pcnt_counter_clear(PCNT_UNIT_3);
  pcnt_counter_resume(PCNT_UNIT_1);
    //pcnt_counter_resume(PCNT_UNIT_2);
    //pcnt_counter_resume(PCNT_UNIT_3);
    }
    fan0_rpm = (fan0_rpm / 2.0) * 30.0;
    fan1_rpm = (fan1_rpm / 2.0) * 30.0;
    fan2_rpm = (fan2_rpm / 2.0) * 30.0;

  if (pos < 1) {
    encoder.setCount(0);
    //value = 0;
    neopixelWrite(led_pin, 0, 0, 50);
    }

  else if (pos > 99) {
    encoder.setCount(100);
    //value = 100;
    neopixelWrite(led_pin, 50, 0, 0);
    }

  else {
    neopixelWrite(led_pin, 0, 50, 0);
    }

  if (mode == 4) { // mode 4 changes all fans
    fan0_pwm = map(value, 0, 100, 0, 255);
    fan1_pwm = map(value, 0, 100, 0, 255);
    fan2_pwm = map(value, 0, 100, 0, 255);
    fan3_pwm = map(value, 0, 100, 0, 255);
  }

  if (fan0_pwm == 0 && fan1_pwm == 0 && fan2_pwm == 0 && fan3_pwm == 0) { // turns of the voltage via SSR if all fans are set to 0
    digitalWrite(enable_pin, LOW);
    Serial.println(" EN PIN LOW");
  }
  else {
    digitalWrite(enable_pin, HIGH);
    Serial.println(" EN PIN HIGH");

    ledcWrite(fan0_pwm_pin, fan0_pwm);
    ledcWrite(fan1_pwm_pin, fan1_pwm);
    ledcWrite(fan2_pwm_pin, fan2_pwm);
    ledcWrite(fan3_pwm_pin, fan3_pwm);
  }

  Serial.print(pos);
  Serial.print(" - ");
  Serial.print(value);
  Serial.print(" - ");
  Serial.print(fan0_pwm);
  Serial.print(" - ");
  Serial.print(fan1_pwm);
  Serial.print(" - ");
  Serial.print(fan2_pwm);
  Serial.print(" - ");
  Serial.print(fan3_pwm);
  Serial.print(" - ");
  Serial.print(fan0_rpm);
  Serial.print(" - ");
  Serial.print(mode);

  server.handleClient();
}

void webRoutes() {

  server.on("/", HTTP_GET, []() {
    File file = LittleFS.open("/index.html", "r");
    if (!file) {
      server.send(404, "text/plain", "index not found");
      return;
    }
    server.streamFile(file, "text/html");
    file.close();
  });

  server.on("/static/bootstrap.bundle.min.js", HTTP_GET, []() {
    //File file = LittleFS.open("/static/bootstrap.bundle.min.js", "r");
    //if (!file) {
    //  server.send(404, "text/plain", "bootstrapjs not found");
    //  return;
    //}
    //server.streamFile(file, "text/html");
    //file.close();
  });

  server.on("/static/bootstrap.min.css", HTTP_GET, []() {
    //File file = LittleFS.open("/static/bootstrap.min.css", "r");
    //if (!file) {
    //  server.send(404, "text/plain", "css not found");
    //  return;
    //}
    //server.streamFile(file, "text/css");
    //file.close();
  });

    server.on("/set", HTTP_GET, []() {
    if (server.hasArg("value")) {
      //value = server.arg("value").toInt();
      encoder.setCount(server.arg("value").toInt());
      mode = 4;
    }
    if (server.hasArg("fan0")) {
      fan0_pwm = server.arg("fan0").toInt();
      fan0_pwm = map(fan0_pwm, 0, 100, 0, 255);
      mode = 3;
    }
    if (server.hasArg("fan1")) {
      fan1_pwm = server.arg("fan1").toInt();
      fan1_pwm = map(fan1_pwm, 0, 100, 0, 255);
      mode = 3;
    }
    if (server.hasArg("fan2")) {
      fan2_pwm = server.arg("fan2").toInt();
      fan2_pwm = map(fan2_pwm, 0, 100, 0, 255);
      mode = 3;
    }
    if (server.hasArg("fan3")) {
      fan3_pwm = server.arg("fan3").toInt();
      fan3_pwm = map(fan3_pwm, 0, 100, 0, 255);
      mode = 3;
    }
    server.send(200, "text/plain", "Parameters updated successfully!");
    });
  }

void init_pcnt() {

    pcnt_config_t pcnt_config_0 = {
        .pulse_gpio_num = 11,
        .ctrl_gpio_num = -1,
        .lctrl_mode = PCNT_MODE_KEEP,  // Control mode when control signal is low
        .hctrl_mode = PCNT_MODE_KEEP,  // Control mode when control signal is high
        .pos_mode = PCNT_COUNT_INC,  // Count up on the positive edge
        .neg_mode = PCNT_COUNT_DIS,  // INC, DIS, KEEP
        .counter_h_lim = 1024,  // Maximum count value
        .counter_l_lim = -1024, // Minimum count value
        .unit = PCNT_UNIT_1 ,  // PCNT unit
        .channel = PCNT_CHANNEL_0
    };

    pcnt_unit_config(&pcnt_config_0);     // Initialize PCNT unit
    pcnt_set_filter_value(PCNT_UNIT_1 , 10);
    pcnt_filter_enable(PCNT_UNIT_1);
    pcnt_event_enable(PCNT_UNIT_1 , PCNT_EVT_H_LIM);
    //pcnt_event_enable(PCNT_UNIT, PCNT_EVT_L_LIM);
    pcnt_event_enable(PCNT_UNIT_1 , PCNT_EVT_ZERO);
    pcnt_intr_enable(PCNT_UNIT_1);
    pcnt_counter_pause(PCNT_UNIT_1);
    pcnt_counter_clear(PCNT_UNIT_1);
    pcnt_counter_resume(PCNT_UNIT_1);

}

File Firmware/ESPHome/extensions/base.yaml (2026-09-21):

# ==========================================
# POWER SUPPLY ENABLE LOGIC
# ==========================================
switch:
  - platform: gpio
    pin: 44
    id: psu_enable
    name: "Power Supply Enable"
    restore_mode: ALWAYS_OFF
# ==========================================
# POWER SUPPLY ENABLE LOGIC
# ==========================================
interval:
  - interval: 500ms
    then:
      - if:
          condition:
            lambda: |-
              return (id(fan0).state || 
                      id(fan1).state || 
                      id(fan2).state || 
                      id(fan3).state);
          then:
            - switch.turn_on: psu_enable
          else:
            - switch.turn_off: psu_enable

# ==========================================
# FAN PWM OUTPUTS
# ==========================================
output:
  - platform: ledc
    id: fan0_pwm
    pin: 13
    frequency: 25000 Hz
  - platform: ledc
    id: fan1_pwm
    pin: 12
    frequency: 25000 Hz
  - platform: ledc
    id: fan2_pwm
    pin: 2
    frequency: 25000 Hz
  - platform: ledc
    id: fan3_pwm
    pin: 1
    frequency: 25000 Hz

# ==========================================
# FAN ENTITIES
# ==========================================
fan:
  - platform: speed
    output: fan0_pwm
    name: "Fan 0"
    id: fan0
    restore_mode: ALWAYS_OFF
  - platform: speed
    output: fan1_pwm
    name: "Fan 1"
    id: fan1
    restore_mode: ALWAYS_OFF
  - platform: speed
    output: fan2_pwm
    name: "Fan 2"
    id: fan2
    restore_mode: ALWAYS_OFF
  - platform: speed
    output: fan3_pwm
    name: "Fan 3"
    id: fan3
    restore_mode: ALWAYS_OFF

# ==========================================
# RPM SENSORS
# ==========================================
sensor:
  - platform: pulse_counter
    pin: 11
    name: "Fan 0 RPM"
    id: fan0_rpm
    unit_of_measurement: "RPM"
    update_interval: 2s
    filters:
      - multiply: 0.5 # 2 Pulse per round
  - platform: pulse_counter
    pin: 10
    name: "Fan 1 RPM"
    id: fan1_rpm
    unit_of_measurement: "RPM"
    update_interval: 2s
    filters:
      - multiply: 0.5
  - platform: pulse_counter
    pin: 9
    name: "Fan 2 RPM"
    id: fan2_rpm
    unit_of_measurement: "RPM"
    update_interval: 2s
    filters:
      - multiply: 0.5
  - platform: pulse_counter
    pin: 8
    name: "Fan 3 RPM"
    id: fan3_rpm
    unit_of_measurement: "RPM"
    update_interval: 2s
    filters:
      - multiply: 0.5

# ==========================================
# RGB LED
# ==========================================
light:
  - platform: esp32_rmt_led_strip
    pin: 21
    num_leds: 1
    rgb_order: GRB
    chipset: WS2812
    name: "Board Status LED"

# ==========================================
# BOOT BUTTON & FACTORY RESET
# ==========================================
button:
  - platform: factory_reset
    name: "Factory Reset Action"
    id: factory_reset_btn

binary_sensor:
  - platform: gpio
    pin:
      number: 0
      inverted: true
      mode:
        input: true
        pullup: true
    id: boot_button
    name: "Boot Button"
    filters:
      - delayed_on: 5s
    on_press:
      - button.press: factory_reset_btn
# ==========================================
# UPTIME
# ==========================================
text_sensor:
  - platform: uptime
    name: "Uptime"
    icon: mdi:clock-outline
    id: uptime_text
    

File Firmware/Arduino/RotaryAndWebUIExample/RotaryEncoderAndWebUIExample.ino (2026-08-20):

#include <Arduino.h>
#include <esp32-hal-ledc.h>
#include <driver/pulse_cnt.h>
#include "driver/gpio.h"
#include <WiFi.h>
#include <WebServer.h>
#include <WebSocketsServer.h> // You have to install the Websockets lib by Markus Sattler (ver 2.7.2) https://github.com/Links2004/arduinoWebSockets

const char* ap_ssid = "The Airflow Project";
const char* ap_pass = "TheAirFlowSetup";
bool new_wlan_data_recieved = false;
String pendingSSID = "";
String pendingPass = "";
const unsigned long WIFI_TIMEOUT_MS = 10000;
extern const char page_index[] PROGMEM;
extern const char page_config[] PROGMEM;

const int led_pin = 21;         
const int max_brightness = 50;  

volatile int current_r = 0;
volatile int current_g = 0;
volatile int current_b = 0;

const int enable_pin = 44;   
const int fan0_pwm_pin = 13; 
const int fan1_pwm_pin = 12; 
const int fan2_pwm_pin = 2;  
const int fan3_pwm_pin = 1;

const int fan_rpm_pins[4] = {11, 10, 9, 8};
volatile int current_rpm[4] = {0, 0, 0, 0};
pcnt_unit_handle_t pcnt_units[4];

const int pwm_frequency = 25000; 
const int pwm_resolution = 8; 

const int pinA = 5; 
const int pinB = 4; 

volatile long encoderValue = 0;
volatile long currentValue;
volatile bool moved;
volatile unsigned long lastInterruptTime = 0;

volatile bool encoderMoved = true; 

volatile unsigned long lastMoveTime = 0;
volatile bool needsFadeOut = false;

unsigned long lastUpdate = 0;


const int CS_PIN = 7;             
const float R_CS = 330.0;         
const float K_CS = 1000.0;          
const float SYSTEM_VOLTAGE = 12.0;
const float I_LIMIT = 2.466;      
float zero_offset_mv = 0.0;


WebServer server(80);
WebSocketsServer webSocket = WebSocketsServer(81);

void IRAM_ATTR isr_encoder() {
  unsigned long interruptTime = micros();
  if (interruptTime - lastInterruptTime > 2000) { 
    if (digitalRead(pinA) != digitalRead(pinB)) {
      if (encoderValue < 102) encoderValue += 2; 
    } else {
      if (encoderValue > -2) encoderValue -= 2;   
    }
    
    encoderMoved = true; 
  }
  lastInterruptTime = interruptTime;
}

void webSocketEvent(uint8_t num, WStype_t type, uint8_t * payload, size_t length) {
  switch(type) {
    case WStype_DISCONNECTED:
      Serial.printf("[%u] Client disconnected\n", num);
      break;
    case WStype_CONNECTED:
      Serial.printf("[%u] Client connected!\n", num);
      {
        String initMsg = "{\"slider\":" + String(encoderValue) + "}";
        webSocket.sendTXT(num, initMsg);
      }
      break;
    case WStype_TEXT:
      String msg = (char*)payload;
      Serial.printf("[%u] Message recieved: %s\n", num, msg.c_str());
      
      if (msg.indexOf("\"slider\":") > 0) {
        int index = msg.indexOf(":");
        String valStr = msg.substring(index + 1, msg.length() - 1);
        valStr.replace("\"", "");
        int sliderVal = valStr.toInt();

        Serial.print("New  Slider-Value recieved: ");
        Serial.println(sliderVal);

        encoderValue = sliderVal;
        encoderMoved = true; 
      }
      break;
  }
}

void fadeOutTask(void *parameter) {
  while (1) {
    if (needsFadeOut && (millis() - lastMoveTime > 1000)) {
      
      for (int i = max_brightness; i >= 0; i--) {
        if (millis() - lastMoveTime < 1000) {
          break;
        }
        
        int r = (current_r > 0) ? i : 0;
        int g = (current_g > 0) ? i : 0;
        int b = (current_b > 0) ? i : 0;
        
        rgbLedWrite(led_pin, r, g, b);
        vTaskDelay(15 / portTICK_PERIOD_MS); 
      }
      
      if (millis() - lastMoveTime > 1000) {
        needsFadeOut = false; 
        rgbLedWrite(led_pin, 0, 0, 0);
      }
    }
    vTaskDelay(50 / portTICK_PERIOD_MS); 
  }
}

void task_read_rpm(void *pvParameters) {
  TickType_t xLastWakeTime = xTaskGetTickCount();
  const TickType_t xFrequency = pdMS_TO_TICKS(1000);

  while (true) {
    vTaskDelayUntil(&xLastWakeTime, xFrequency);

    for (int i = 0; i < 4; i++) {
      int pulse_count = 0;
      
      pcnt_unit_get_count(pcnt_units[i], &pulse_count);
      pcnt_unit_clear_count(pcnt_units[i]);

      current_rpm[i] = pulse_count * 30;
    }
  }
}

void WlanConnect();
void WlanDelete();
void WlanAdd(String InputSSID, String InputPasswort);
void WebRoutes();
void init_fan_pcnt();
float AnalogReadOut();
float calibrateZero(int pin);

void setup() {
  pinMode(enable_pin, OUTPUT); 
  digitalWrite(enable_pin, LOW);

  Serial.begin(115200);
  analogReadResolution(12);
  analogSetAttenuation(ADC_11db);
  delay(1000);
  zero_offset_mv = calibrateZero(CS_PIN);
  delay(1000);
  
  WlanConnect();
  WebRoutes();
  init_fan_pcnt();

  rgbLedWrite(led_pin, 0, 0, 0);

  ledcAttach(fan0_pwm_pin, pwm_frequency, pwm_resolution); 
  ledcAttach(fan1_pwm_pin, pwm_frequency, pwm_resolution);
  ledcAttach(fan2_pwm_pin, pwm_frequency, pwm_resolution);
  ledcAttach(fan3_pwm_pin, pwm_frequency, pwm_resolution);

  pinMode(pinA, INPUT_PULLUP);
  pinMode(pinB, INPUT_PULLUP);
  attachInterrupt(digitalPinToInterrupt(pinA), isr_encoder, CHANGE);

  xTaskCreate(fadeOutTask, "FadeTask", 2048, NULL, 1, NULL);
  xTaskCreatePinnedToCore(task_read_rpm, "RPM_Task",2048, NULL, 1, NULL, 0);

  webSocket.begin();
  webSocket.onEvent(webSocketEvent);
}

void loop() {
  if (encoderMoved) {

    int currentValue = encoderValue;
    if (currentValue < 0) currentValue = 0;
    if (currentValue > 100) currentValue = 100;

    encoderValue = currentValue; 


    String jsonString = "{\"slider\":" + String(currentValue) + "}";
    

    webSocket.broadcastTXT(jsonString);
    
    Serial.print("Encoder changed to: ");
    Serial.println(currentValue);
  }

  noInterrupts();
  currentValue = encoderValue;
  moved = encoderMoved;
  encoderMoved = false;
  interrupts();

  if (moved) {
    
    lastMoveTime = millis();
    needsFadeOut = true;    

    int pwm_signal = map(currentValue, 0, 100, 0, 255);
    pwm_signal = constrain(pwm_signal, 0, 255);

    ledcWrite(fan0_pwm_pin, pwm_signal);
    ledcWrite(fan1_pwm_pin, pwm_signal);
    ledcWrite(fan2_pwm_pin, pwm_signal);
    ledcWrite(fan3_pwm_pin, pwm_signal);

    if (currentValue >= 100) { 
      current_r = max_brightness; current_g = 0; current_b = 0;
    } else if (currentValue <= 0) { 
      current_r = 0; current_g = max_brightness; current_b = 0;
    } else { 
      current_r = 0; current_g = 0; current_b = max_brightness;
    }
    
    rgbLedWrite(led_pin, current_r, current_g, current_b);
      
    if (pwm_signal == 0) {
      digitalWrite(enable_pin, LOW);
    } else {
      digitalWrite(enable_pin, HIGH);
    }

    Serial.print("Position: ");
    Serial.println(currentValue);
    Serial.println(pwm_signal);

  }
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

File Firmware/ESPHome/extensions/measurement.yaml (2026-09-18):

globals:
  - id: zero_offset_mv
    type: float
    initial_value: '0.0'

esphome:
  name: smart-fan-controller
  
  on_boot:
    priority: 250 
    then:
      - lambda: |-
          ESP_LOGI("stromsensor", "Kalibriere ADC Nullpunkt...");
          uint32_t sum = 0;
          
          for (int i = 0; i < 50; i++) {
            sum += analogReadMilliVolts(7); // Pin 7 direkt auslesen
            delay(5); 
          }
          
          id(zero_offset_mv) = sum / 50.0;
          ESP_LOGI("stromsensor", "Fertig! Grundrauschen liegt bei %.1f mV", id(zero_offset_mv));

sensor:

  - platform: template
    name: Fan Power Consumption"
    id: system_power
    unit_of_measurement: "W"
    device_class: "power"
    state_class: "measurement"
    update_interval: 1s
    lambda: |-
      const float R_CS = 330.0;        
      const float K_CS = 500.0;          
      const float SYSTEM_VOLTAGE = 12.0;
      const float I_LIMIT = 2.466;   
      const float BOARD_CALIBRATION = 1.087;
      
      uint32_t sum_mv = 0;
      const int NUM_SAMPLES = 10;
      
      // 10 Samples
      for (int i = 0; i < NUM_SAMPLES; i++) {
        sum_mv += analogReadMilliVolts(7);
        delay(2);
      }
      
      float raw_mv = (sum_mv / (float)NUM_SAMPLES);
      
      float corrected_mv = raw_mv - id(zero_offset_mv);
      
      if (corrected_mv < 0.0) {
        corrected_mv = 0.0;
      }
      
      float v_cs = corrected_mv / 1000.0;
      float current_A = ((v_cs / R_CS) * K_CS) * BOARD_CALIBRATION;
      float power_W = current_A * SYSTEM_VOLTAGE;

      if (current_A >= (I_LIMIT - 0.05)) {
        ESP_LOGW("stromsensor", "WARNING: HARDWARE-CURRENT LIMIT! (%.2f A)", current_A);
      }

      return power_W;

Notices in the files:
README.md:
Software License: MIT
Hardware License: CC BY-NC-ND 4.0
